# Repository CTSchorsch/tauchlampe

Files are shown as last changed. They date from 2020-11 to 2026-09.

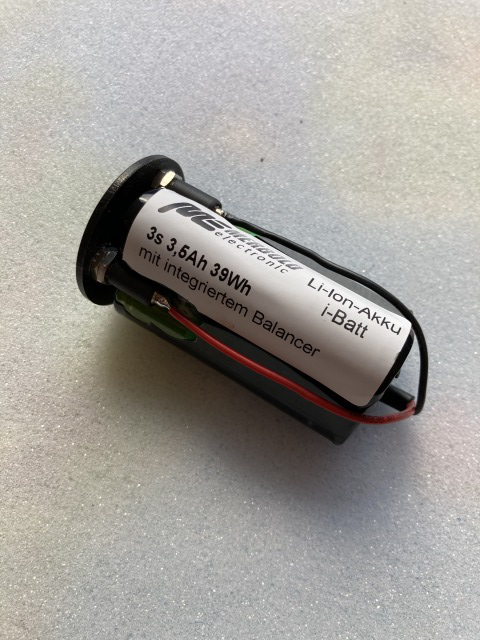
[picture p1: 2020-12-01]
doc/bilder/v4.2/Batteriefach8.JPG

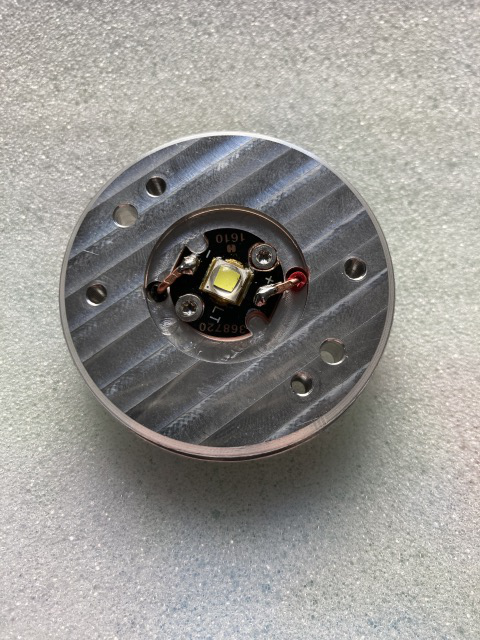
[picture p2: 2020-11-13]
doc/bilder/v4.2/led.jpg

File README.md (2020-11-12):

# tauchlampe

10W LED Tanklampe mit Goodmanhandle

Version 4.2
- neues PCB, einseitig, liegt direkt auf der LED-Aufnahme auf, JST Stecker für Taster und Power
- Abdeckung für PCB
- LED-Aufnahme für Produktion vereinfacht
- Deckel für Akkufach: 2 Bananenbuchsen zum laden, Durchführung für JST Kabel

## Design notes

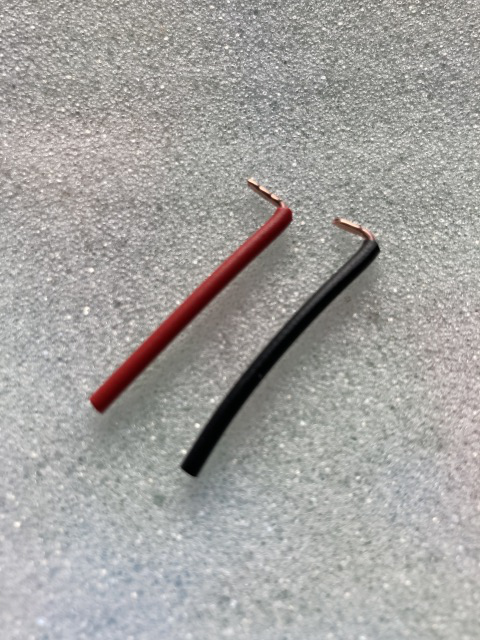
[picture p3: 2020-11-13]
doc/bilder/v4.2/zuleitung.jpg

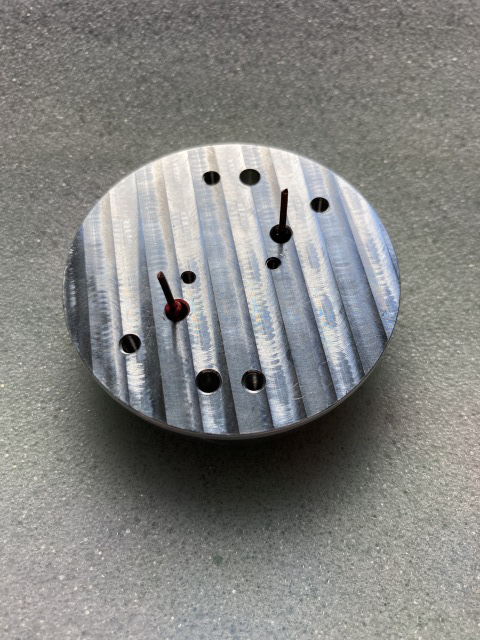
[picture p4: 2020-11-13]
doc/bilder/v4.2/led2.jpg

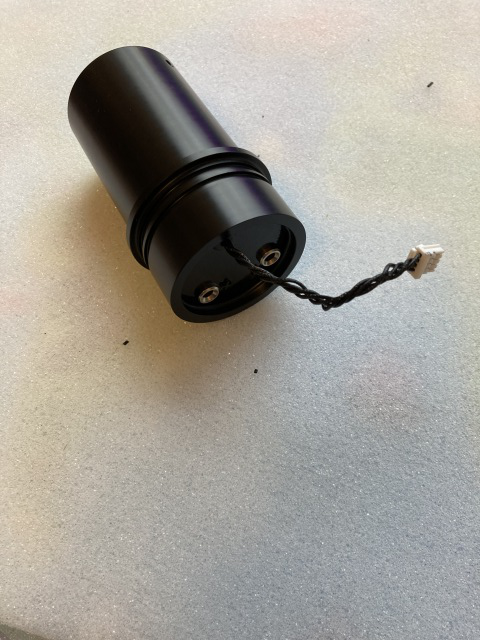
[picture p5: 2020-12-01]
doc/bilder/v4.2/Batteriefach12.JPG

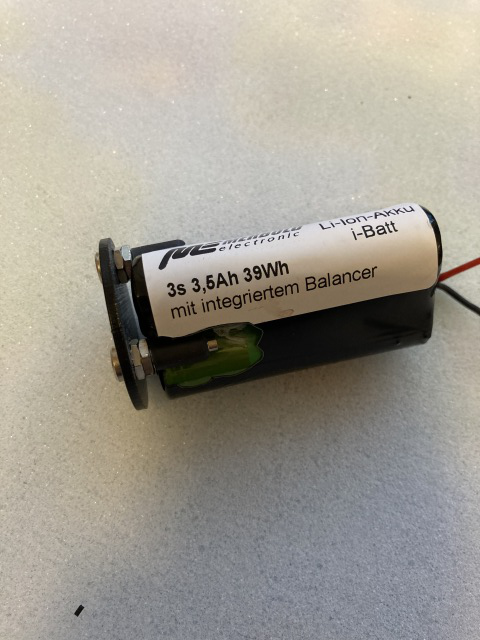
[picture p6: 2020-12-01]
doc/bilder/v4.2/Batteriefach7.JPG

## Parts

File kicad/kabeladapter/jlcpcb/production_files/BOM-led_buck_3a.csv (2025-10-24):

Comment | Designator | Footprint | LCSC | Quantity
MWSA0603-100MT | L1 | L_Sumida_CDMC6D28_7.25x6.5mm | C132141 | 1
MAX16820ATT | U1 | SON95P300X300X80-7N | C143371 | 1
10k0 | R2 | R_0805_2012Metric | C17414 | 1
4n70 | C7 | C_0805_2012Metric | C1744 | 1
4k75 | R5 | R_0805_2012Metric | C17672 | 1
68k1 | R4 | R_0805_2012Metric | C17771 | 1
825k | R3 | R_0805_2012Metric | C17835 | 1
SS54 | D1 | D_SMA | C22452 | 1
LED blau | D2 | LED_0805_2012Metric | C2293 | 1
22u0 / 25V | C4,C5 | C_0805_2012Metric | C45783 | 2
100n | C2,C6 | C_0805_2012Metric | C49678 | 2
0R070 | R1 | R_2512_6332Metric | C76251 | 1
22u0 / 25V | C1 | C_0805_2012Metric | C90143 | 1
Conn_02x03_Odd_Even | J3 | PinHeader_2x03_P2.00mm_Vertical_SMD |  | 1
ATtiny1616-M | U2 | VQFN-20-1EP_3x3mm_P0.4mm_EP1.7x1.7mm |  | 1
M1 | H1 | MountingHole_3.2mm_M3 |  | 1
M2 | H2 | MountingHole_3.2mm_M3 |  | 1
BSC022N04LSATMA | Q1 | TDSON-8-1 |  | 1
470r | R8 | R_0805_2012Metric |  | 1
TestPoint | TP1 | TestPoint_Pad_1.0x1.0mm |  | 1
Conn_01x05 | J4 | PinHeader_1x05_P2.00mm_Vertical |  | 1
TestPoint | TP4 | TestPoint_Pad_1.0x1.0mm |  | 1
LED+ | J1 | TestPoint_Plated_Hole_D3.0mm |  | 1
LED- | J2 | TestPoint_Plated_Hole_D3.0mm |  | 1

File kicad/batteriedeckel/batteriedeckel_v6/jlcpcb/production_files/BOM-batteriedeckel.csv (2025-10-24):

Comment | Designator | Footprint | LCSC | Quantity
Conn_02x03_Odd_Even | J1 | PinSocket_2x03_P2.00mm_Vertical_SMD |  | 1
MountingHole | H2 | MountingHole_3.2mm_M3_DIN965 |  | 1
MountingHole | H1 | MountingHole_3.2mm_M3_DIN965 |  | 1

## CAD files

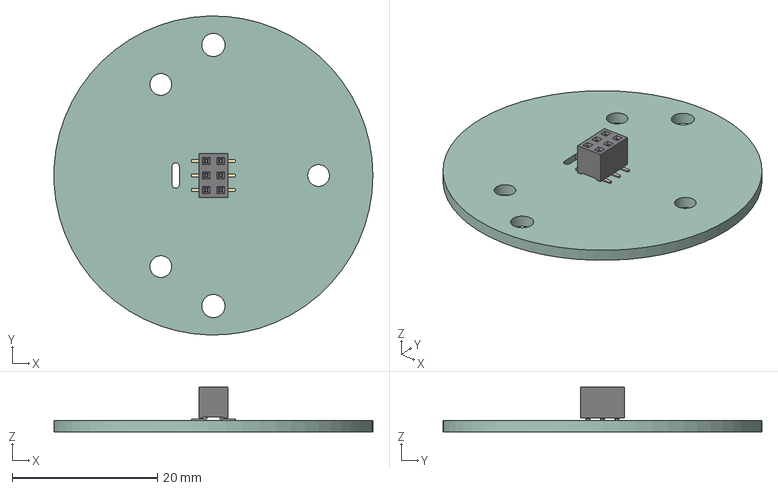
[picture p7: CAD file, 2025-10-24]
kicad/batteriedeckel/batteriedeckel_v6/batteriedeckel.step
44.0 x 44.0 x 6.20 mm
PinSocket_2x03_P2.00mm_Vertical_SMD
batteriedeckel_PCB

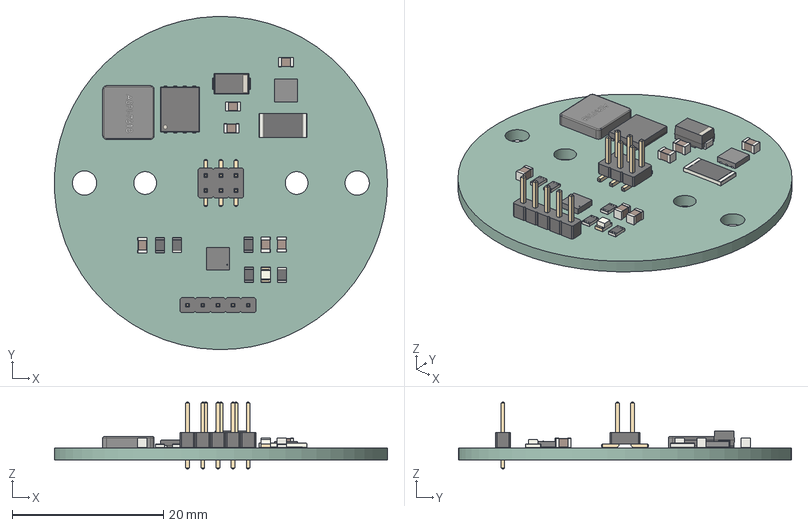
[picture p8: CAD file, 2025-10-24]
kicad/kabeladapter/kabeladapter.step
44.0 x 44.0 x 8.80 mm
C_0805_2012Metric x 6
D_SMA
LED_0805_2012Metric
R_0805_2012Metric x 5
PinHeader_2x03_P200mm_Vertical_SMD
T633+2
ASPI-7318
R_2512_6332Metric
TDSON_8_1
PinHeader_1x05_P200mm_Vertical
_autosave-led_buck_3a_PCB

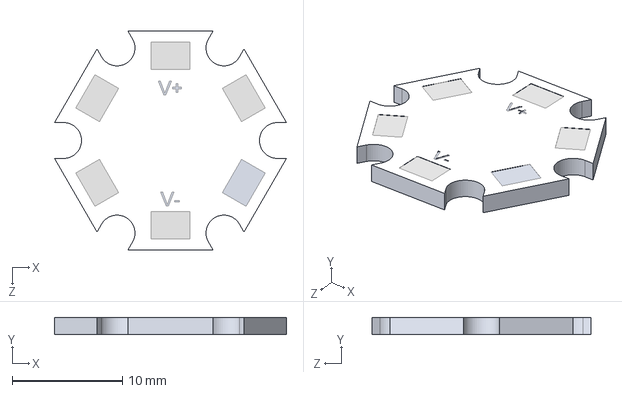
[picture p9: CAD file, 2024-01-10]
mech/cree/User Library-Star-PCB/User Library-Star-PCB.STEP
21.1 x 1.59 x 19.9 mm

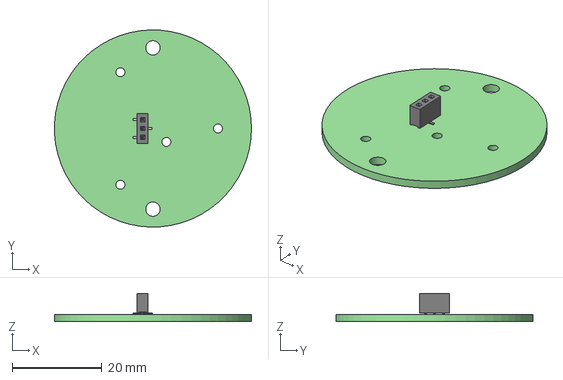
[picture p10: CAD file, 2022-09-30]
mech/PCBs/batteriedeckel.step
44.0 x 44.0 x 6.25 mm
batteriedeckel PCB

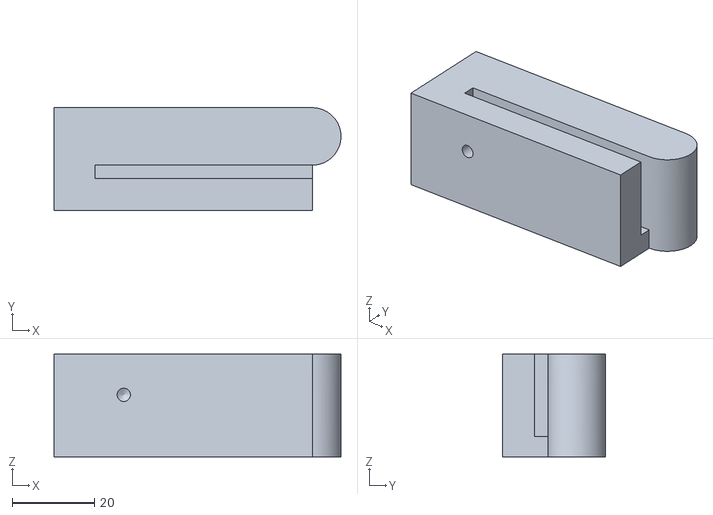
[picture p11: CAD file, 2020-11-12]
mech/Tools/Biegehilfe/Biegehilfe.stl
69.9 x 25.0 x 25.0

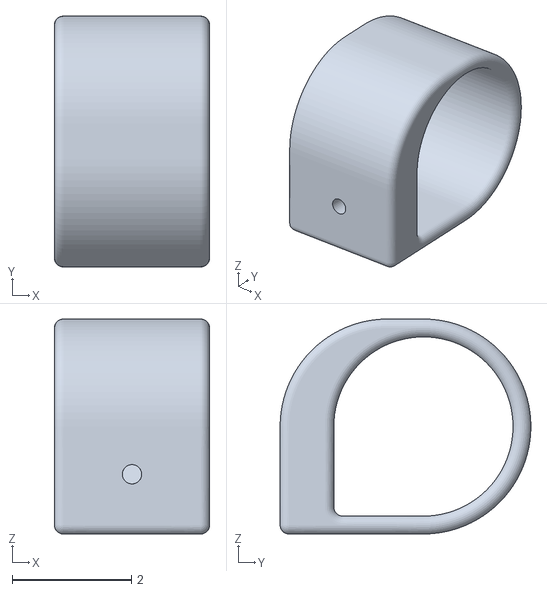
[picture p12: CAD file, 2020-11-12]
mech/Tools/Thumbloop/LoopD.stl
2.60 x 4.20 x 3.60

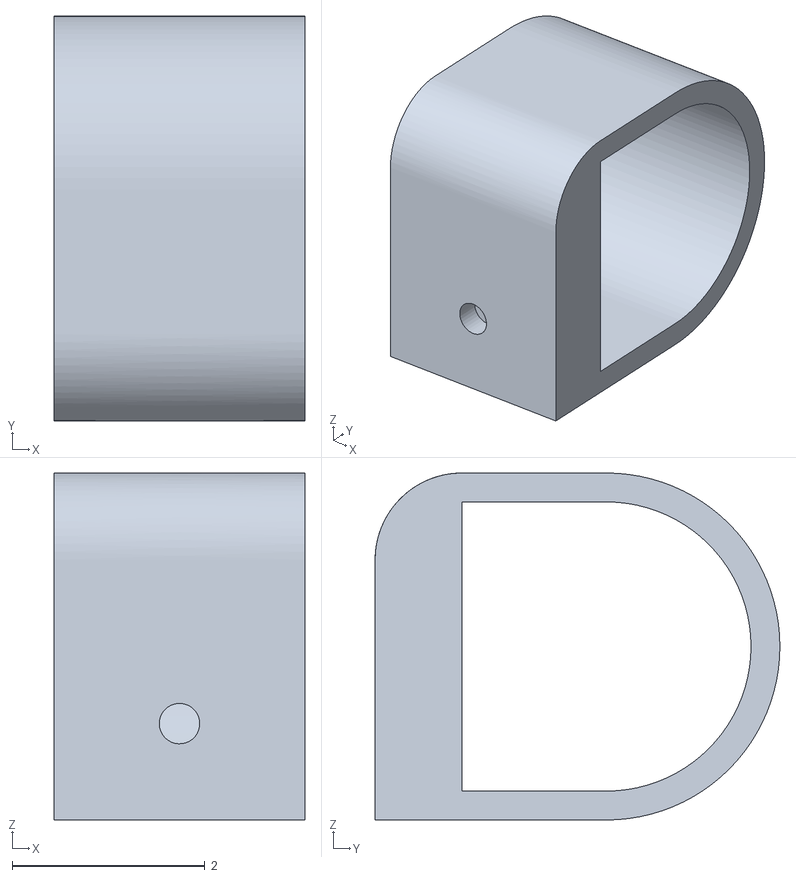
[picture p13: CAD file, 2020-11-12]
mech/Tools/Thumbloop/thumbloopB.stl
2.60 x 4.20 x 3.60

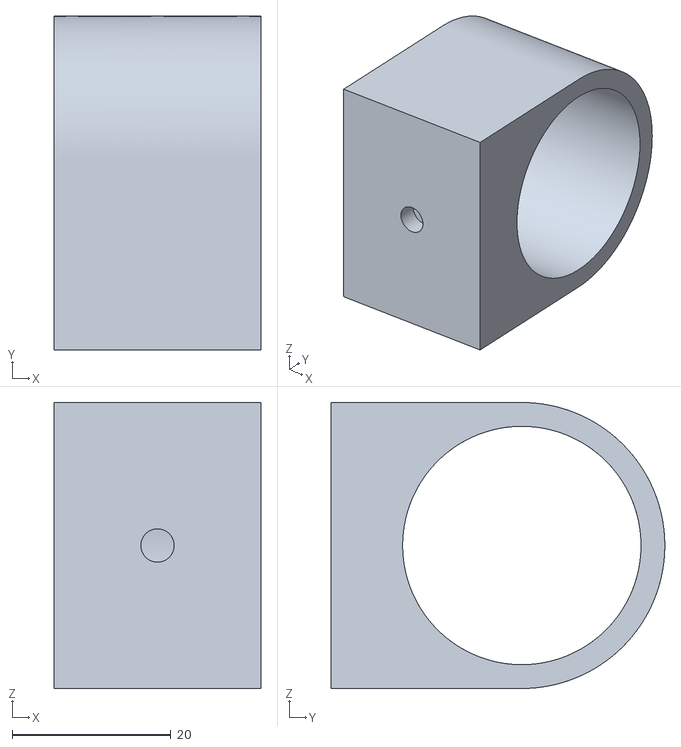
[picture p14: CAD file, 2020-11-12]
mech/Tools/Thumbloop/Bauteil1.stl
26.0 x 42.0 x 36.0

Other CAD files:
mech/Deckel.ipt
mech/Glasscheibe.ipt
mech/Grundplattee.ipt
mech/GrundplatteeThumbloop.ipt
mech/Halteblech.ipt
mech/Haltegriff.ipt
mech/Lampengehäuse.iam
mech/Lampengehäuse.ipt
mech/Lampengehäuse_detail.idw
mech/Lampenkopf.iam
mech/Lampenkopf_4_3.idw
mech/Langmutter.ipt
mech/Ledaufnahme.ipt
mech/O-Ring_40_1_8.ipt
mech/O-Ring_46x1.5.ipt
mech/O-Ring_48_2.ipt
mech/O-Ring_51_2.ipt
mech/O-Ring_51_3.ipt
mech/O-Ring_53_2_5.ipt
mech/O-Ring_55_2.ipt
mech/PCBs/ASPI-7318-100M-T--3DModel-STEP-400430.iam
mech/PCBs/B3B-PH-SM4-TB-LF--SN---3DModel-STEP-56544.iam
mech/PCBs/COMPOUND.ipt
mech/PCBs/COMPOUND_1.ipt
mech/PCBs/COMPOUND_2.ipt
mech/PCBs/C_0805_2012Metric.iam
mech/PCBs/D_SMA.iam
mech/PCBs/LED_0805_2012Metric.iam
mech/PCBs/MAX16820ATT+.iam
mech/PCBs/OldVersions/SOLID.0001.ipt
mech/PCBs/PinHeader_1x05_P2.00mm_Vertical.iam
mech/PCBs/PinSocket_1x03_P2.00mm_Vertical_SMD_Pin1Left.iam
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

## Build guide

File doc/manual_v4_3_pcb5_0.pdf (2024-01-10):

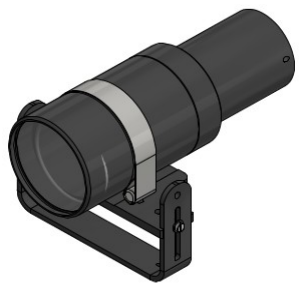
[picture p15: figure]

### Batterien einlegen A

3 Zellen vom Typ 18650 mit hohem Pluspol (button top)

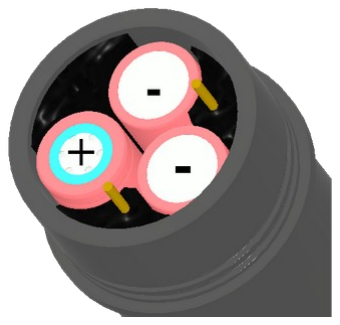
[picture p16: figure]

Flache Zellen können nur verwendet werden wenn die Batteriekontakte mit Lötzinn erhöht werden.

### georg@atc-ev.de

## 10W LED Tauchlampe

Bedienungsanleitung
v4.3a / PCB 5.0

### Inhalt / Hinweis

### Batterien einlegen | A Einschalten und Dimmen | B Umbau auf Kabel / Akkufach | C

Bei einer Akkuspannung von unter 9,2V oder einer Temperatur von >70°C in der Lampe, wird auf 20% gedimmt.

### Einschalten / Dimmen B

Akkufach: „langsames“ Doppeldrücken schaltet EIN, jedes weitere Drücken dimmt auf 70%, 30% und AUS.

Tank: EIN/AUS über Schalter am Tank. Wiederholtes AUS/EIN schalten innerhalb von 5 Sekunden dimmt in den Stufen 100%, 70% und 30%

### Umbau auf Kabel / Akkufach C

Der Anschluss für das Kabel ist unter den Akkukontakten

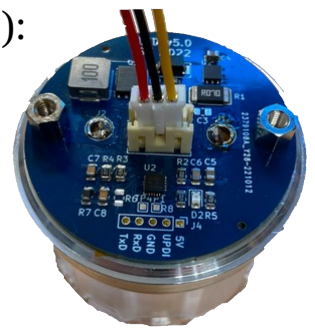
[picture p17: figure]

im Lampengehäuse (2 Schrauben lösen):

- Gelb + Pol (9-18V)
- Schwarz – Pol
- Rot „Modus“ Kontakt:
Für externen Akkutank rot mit schwarz verbinden

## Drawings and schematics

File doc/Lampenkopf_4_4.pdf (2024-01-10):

# D D 10W LED Lampenkopf

# (c) 2020 Georg Schardt

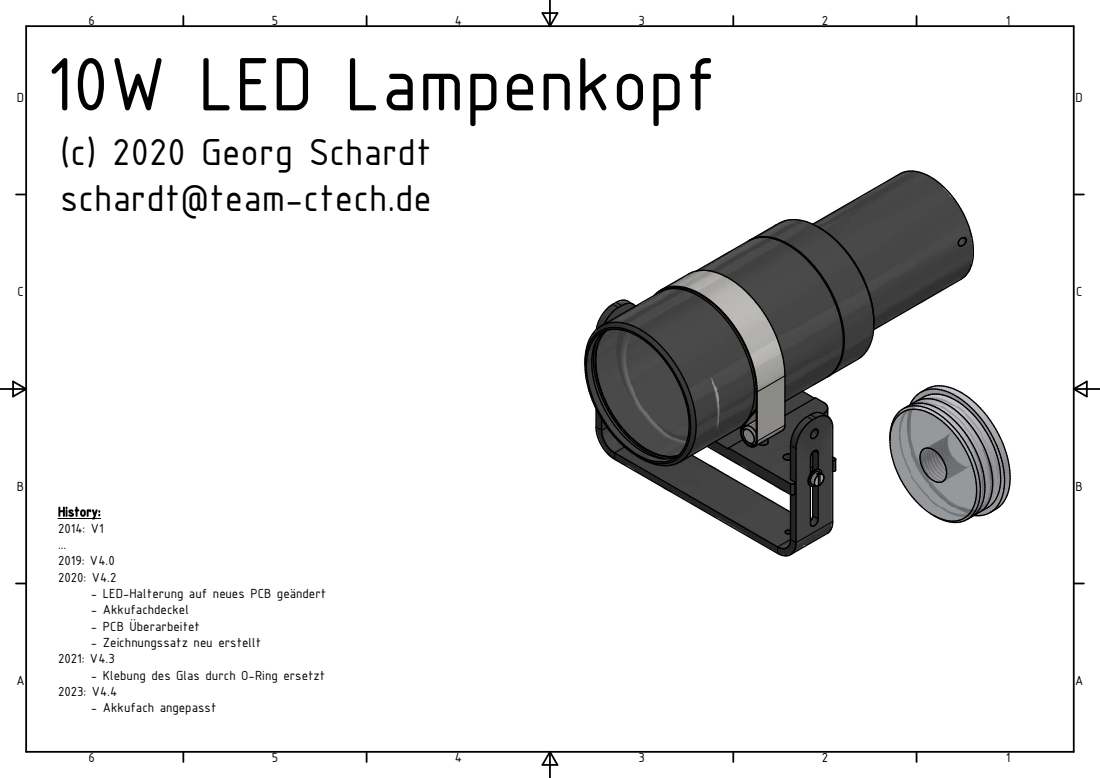
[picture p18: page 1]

schardt@team-ctech.de

History:
- LED-Halterung auf neues PCB geändert
- Akkufachdeckel
- PCB Überarbeitet
- Zeichnungssatz neu erstellt
- Klebung des Glas durch O-Ring ersetzt
- Akkufach angepasst

A A

B B

C C

D D

BAUTEILLISTE
OBJEKT | ANZAHL | BAUTEILNUMMER | BESCHREIBUNG
1 | 1 | GrundplatteeThumbloop
2 | 1 | Lampengehäuse
3 | 1 | Borosilikatglas 55x10
4 | 1 | Ledaufnahme
5 | 1 | Akkufach
6 | 1 | Überwurfmutter
7 | 1 | Haltegriff
8 | 1 | Halteblech
9 | 1 | PCB Buck_3a_v4 | KiCad electronic assembly
10 | 2 | Langmutter
11 | 1 | Gaggione LLH09SPB00 | 3D InterOp IGES (Version 22 0 2), Spatial Corp. Copyright (c) 1999-2007.
12 | 2 | BS 4168 - M4 x 16 | Senkkopf- und Halbrundschrauben mit Innensechskant -metrische Ausführung
13 | 2 | DIN 125 - A 3,2 | Unterlegscheibe
14 | 2 | ISO 1207 - M3 x 4 | Zylinderschraube mit Schlitz
15 | 1 | Gaggione LLC49N
16 | 1 | O-Ring_51_2
17 | 2 | O-Ring_46x1.5
18 | 1 | O-Ring_55_2
19 | 1 | O-Ring_48_2
20 | 1 | O-Ring_40_1_8
21 | 1 | akkuhalterung_deckel_2

C C

D

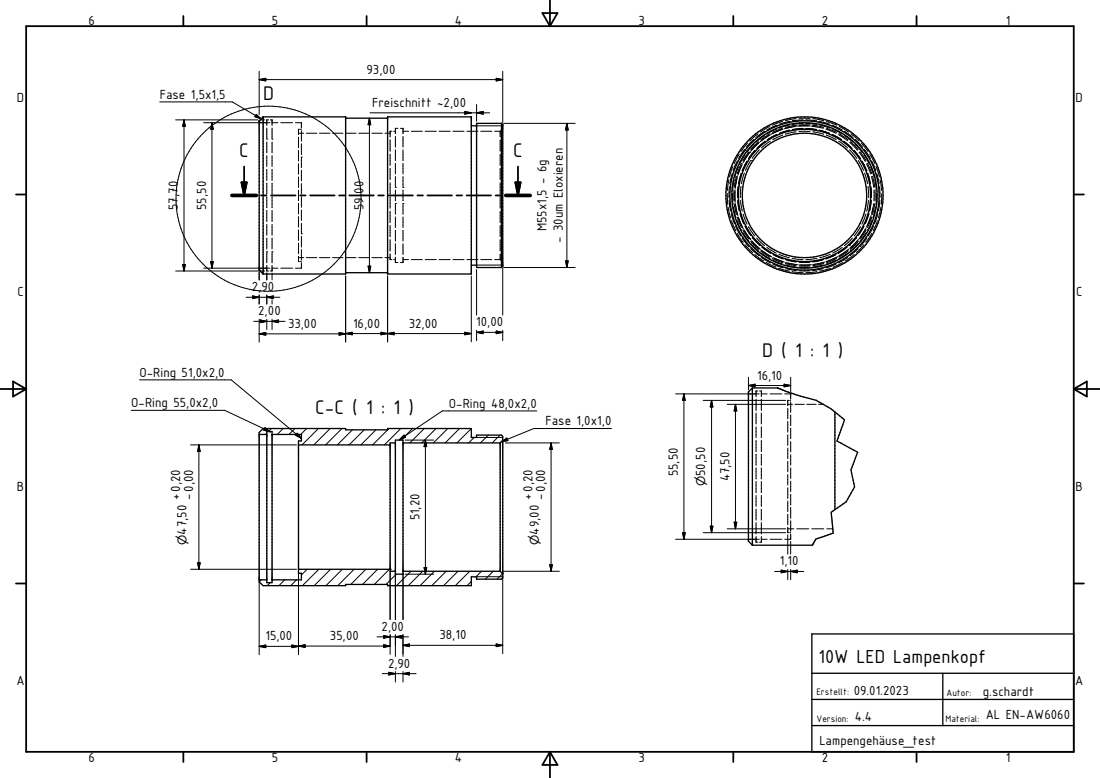
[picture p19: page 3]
Version:; 10W LED Lampenkopf; Material:; Freischnitt ~2,00; M⁵⁵x¹,5 - 6g - 30um Eloxieren 59,00; Fase 1,5x1,5; Fase 1,0x1,0; O-Ring 48,0x2,0; O-Ring 55,0x2,0; O-Ring 51,0x2,0 ⁵⁵,50

Erstellt: 09.01.2023 | Autor: g.schardt

Lampengehäuse_test

## B B 4⁸,80

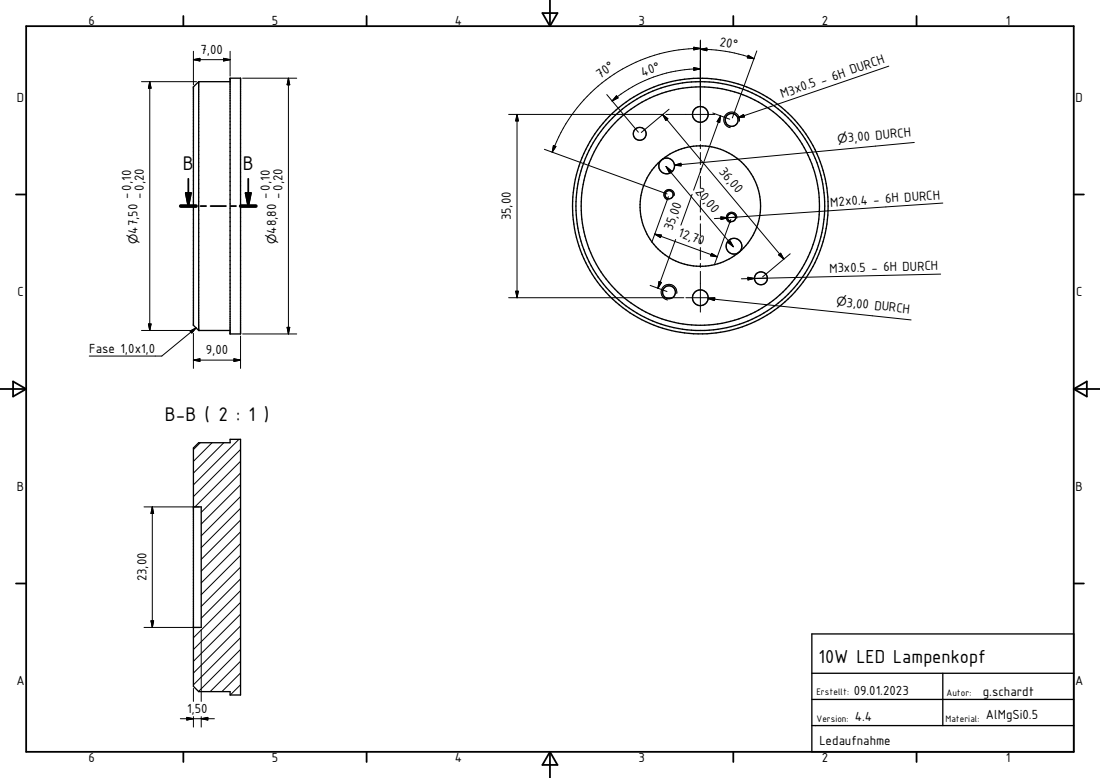
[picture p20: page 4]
10W LED Lampenkopf; Fase 1,0x1,0 ⁴⁷,50; M3x0.5 - 6H DURCH; n3,00 DURCH; M2x0.4 - 6H DURCH; AlMgSi0.5

Erstellt: 09.01.2023 | Autor: g.schardt

Ledaufnahme

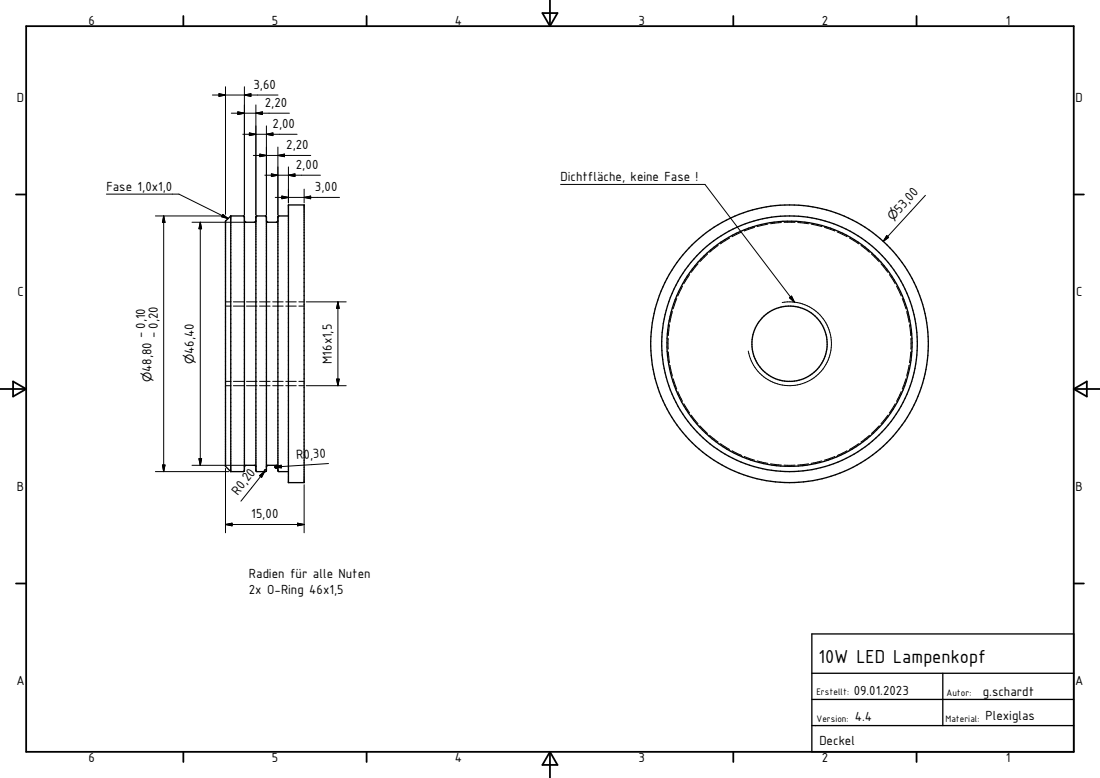
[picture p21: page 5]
10W LED Lampenkopf; 2x O-Ring 46x1,5M¹⁶x¹,5 4⁸,80; Fase 1,0x1,0; Plexiglas

Dichtfläche, keine Fase !

Radien für alle Nuten

Erstellt: 09.01.2023 | Autor: g.schardt

Deckel

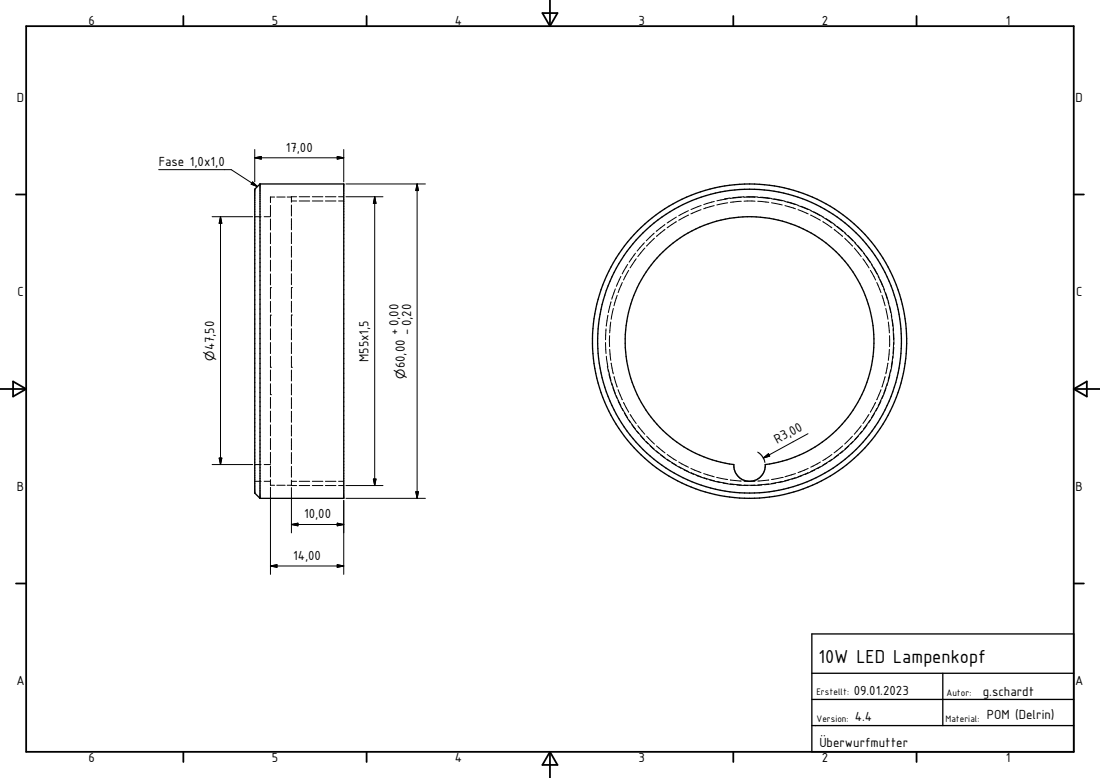
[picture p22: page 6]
10W LED Lampenkopf; Fase 1,0x1,0; POM (Delrin)

Erstellt: 09.01.2023 | Autor: g.schardt

Überwurfmutter

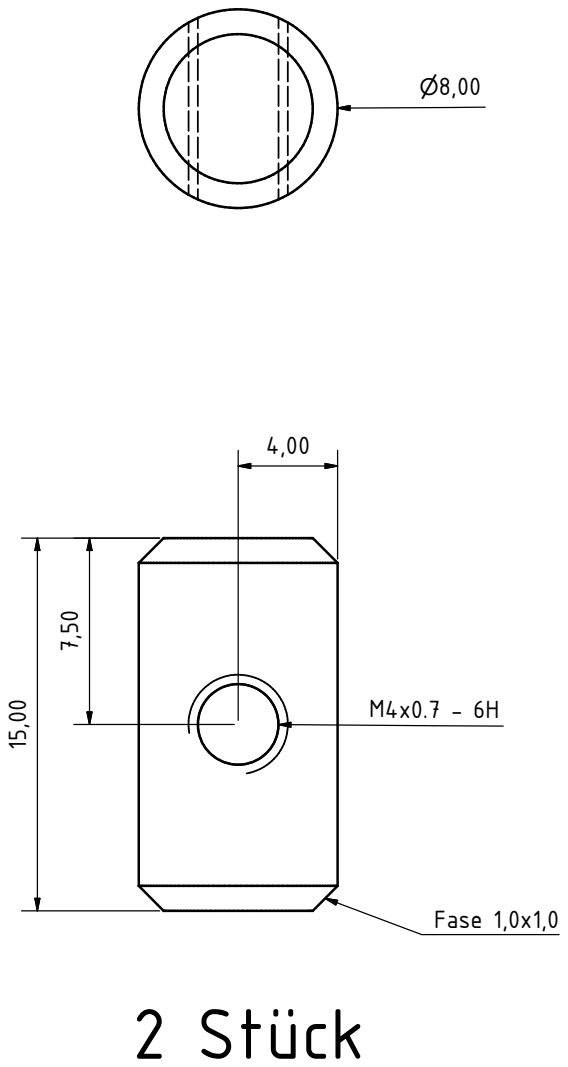
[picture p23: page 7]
10W LED Lampenkopf; Fase 1,0x1,0; 2 Stück

Erstellt: 09.01.2023 | Autor: g.schardt

LANGMUTTER

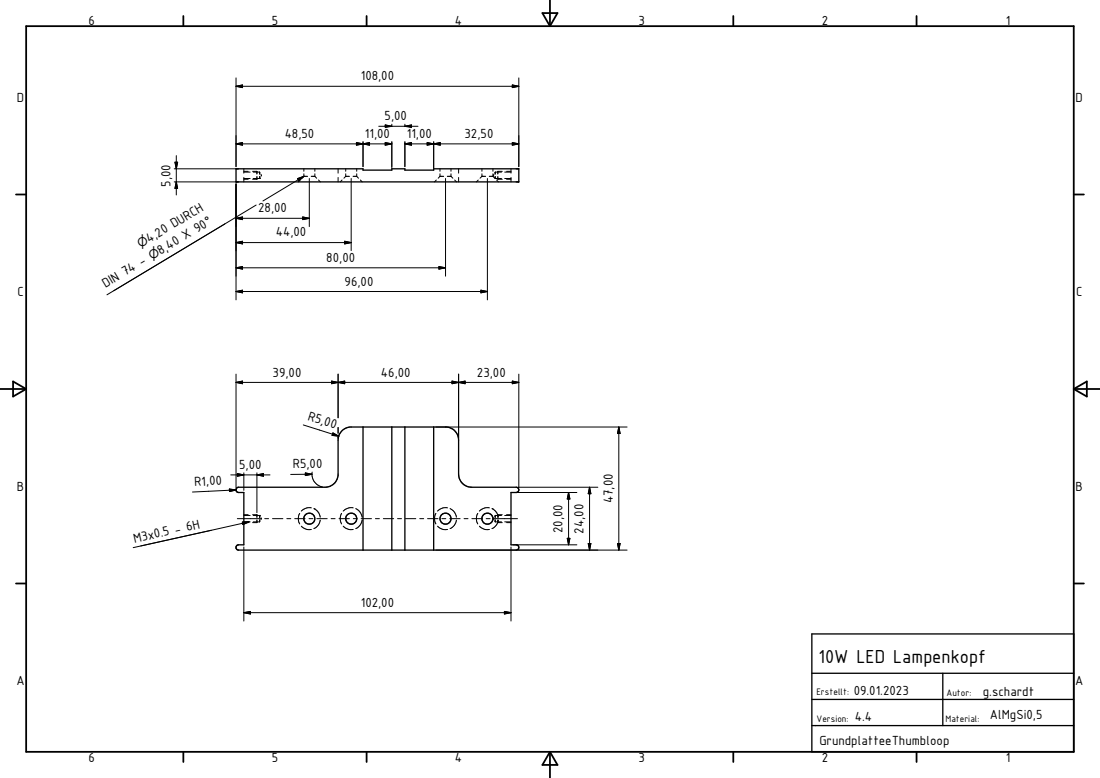
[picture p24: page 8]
10W LED Lampenkopf; Material: AlMgSi0,5 ⁵,00; n4,20 DURCH DIN 74 - n8,40 X 90°

Erstellt: 09.01.2023 | Autor: g.schardt

GrundplatteeThumbloop

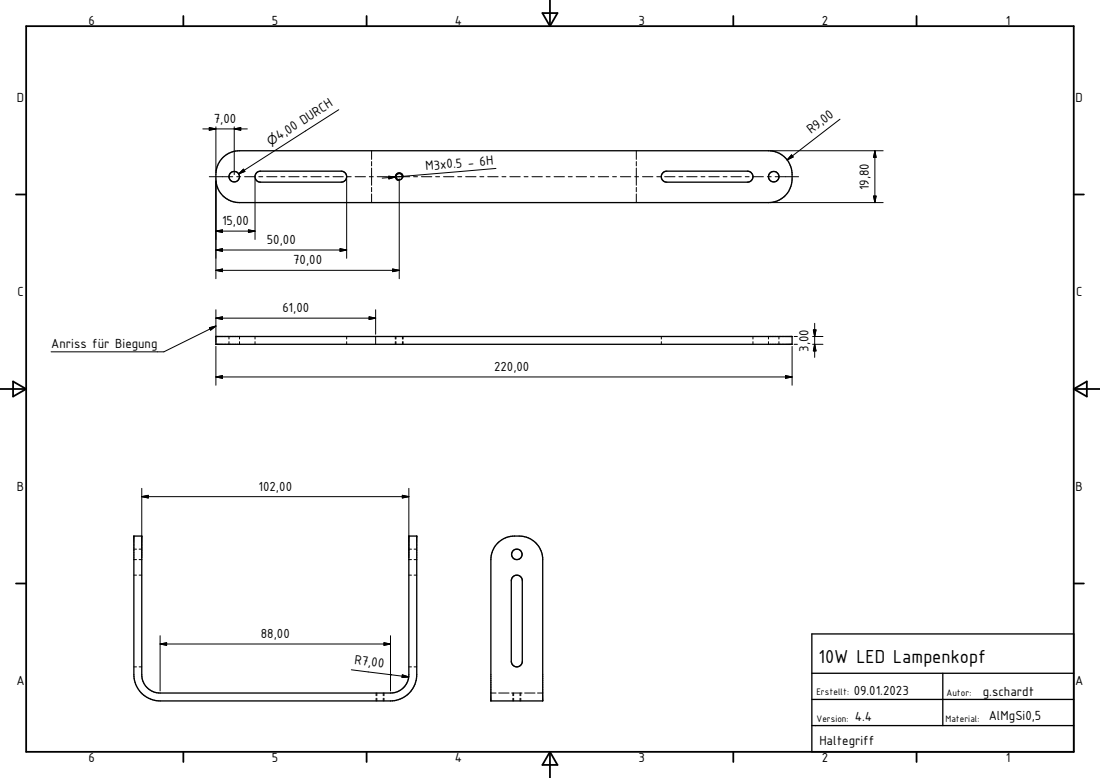
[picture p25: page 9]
Haltegriff; 10W LED Lampenkopf; n4,00 DURCH

Anriss für Biegung

Erstellt: 09.01.2023 | Autor: g.schardt
4.4 | AlMgSi0,5

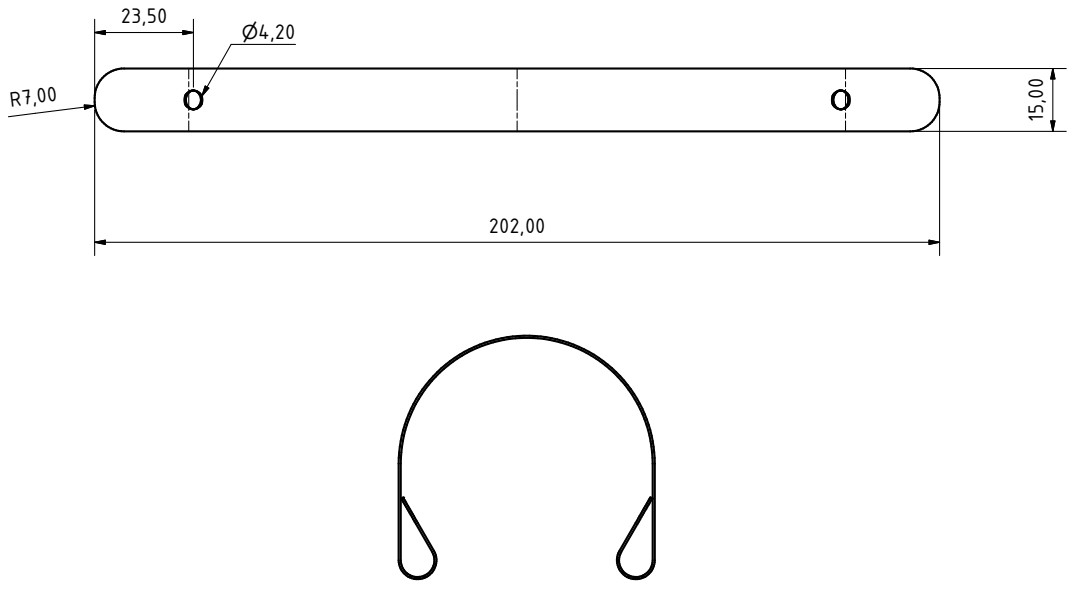
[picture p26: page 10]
10W LED Lampenkopf

Erstellt: 09.01.2023 | Autor: g.schardt

Halteblech

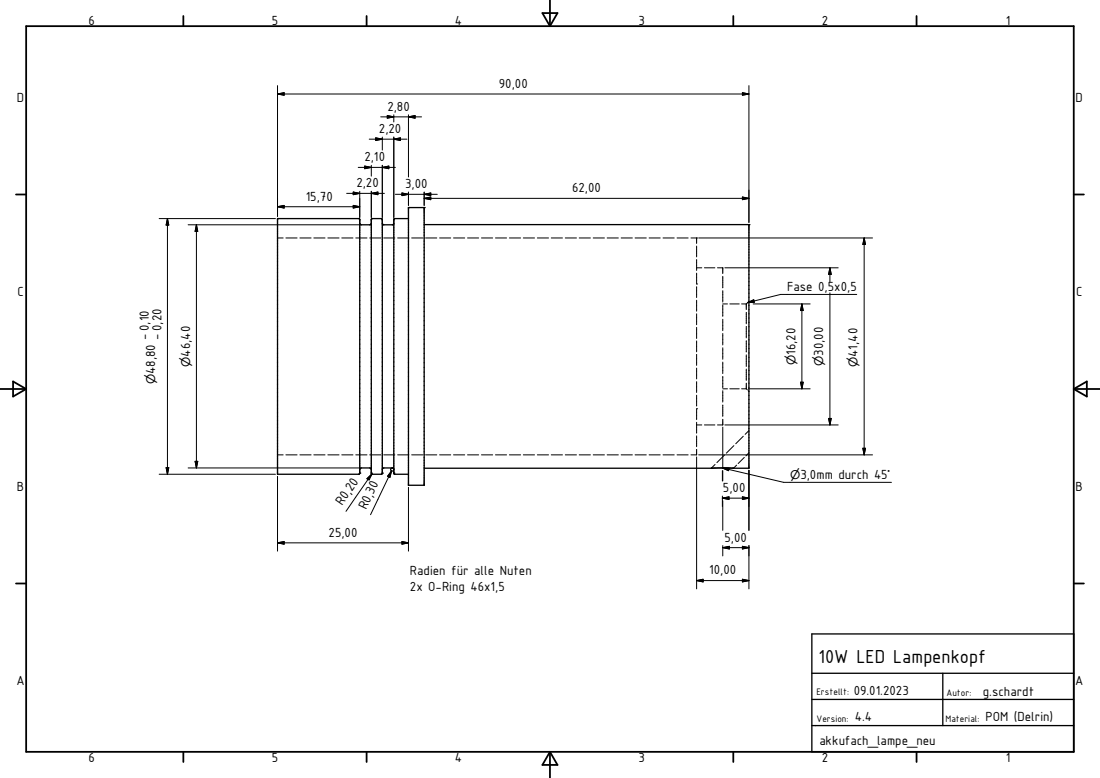
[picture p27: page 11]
10W LED Lampenkopf; Fase 0,5x0,5; n3,0mm durch 45~; POM (Delrin)

Radien für alle Nuten
2x O-Ring 46x1,5

Erstellt: 09.01.2023 | Autor: g.schardt

akkufach_lampe_neu

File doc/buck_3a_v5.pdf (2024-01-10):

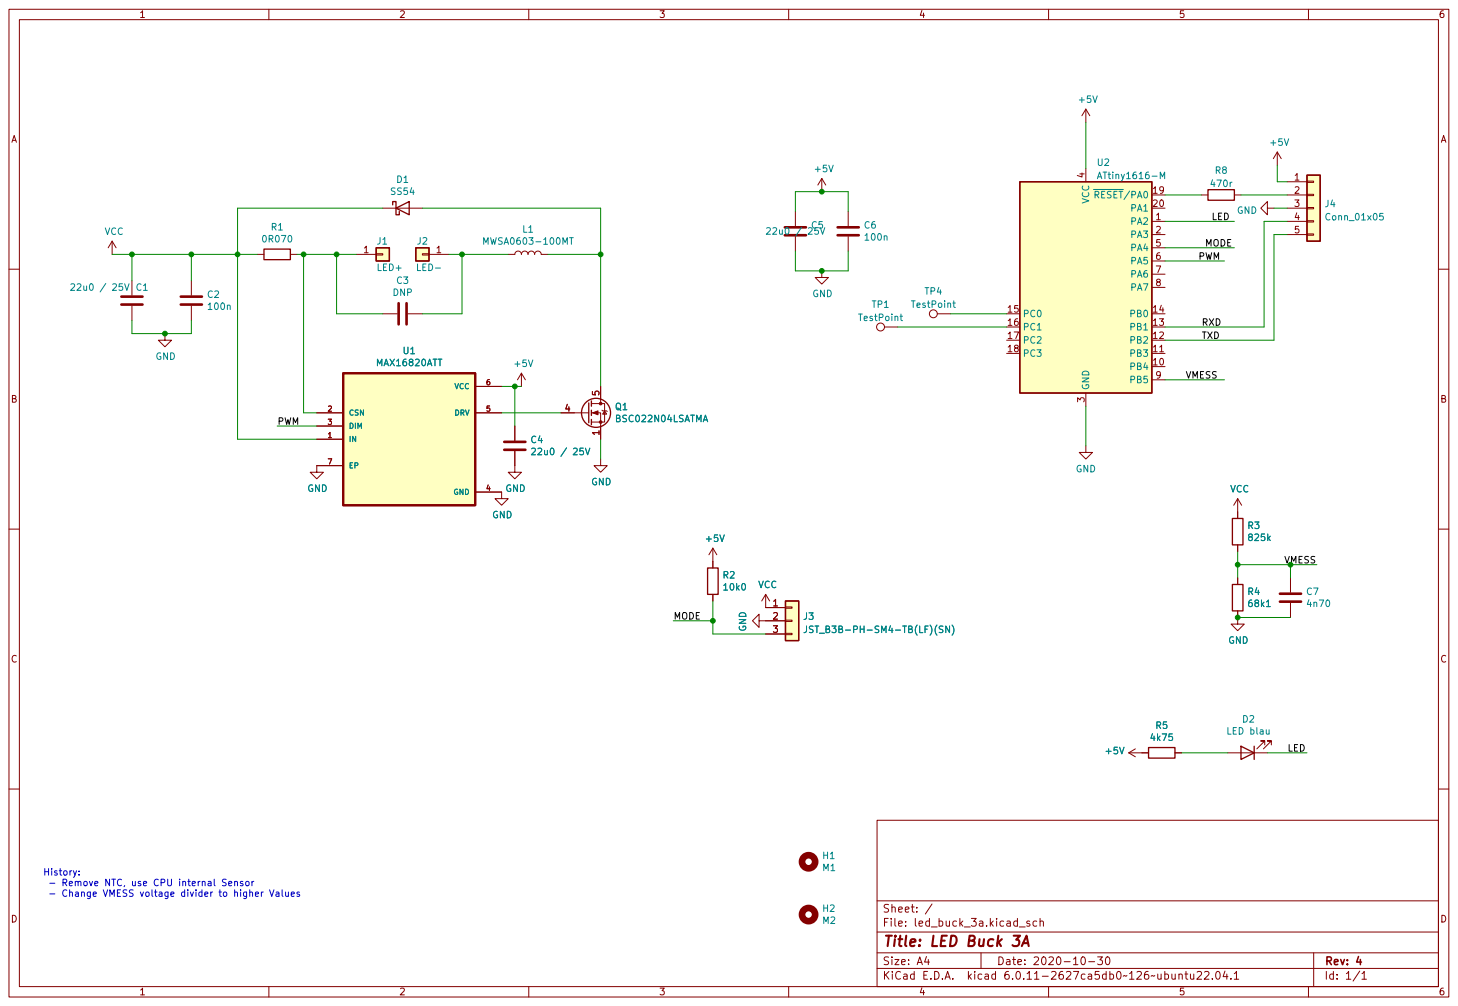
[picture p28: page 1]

JST_B3B-PH-SM4-TB(LF)(SN) 1

File: led_buck_3a.kicad_sch Sheet: /
Id: 1/1 Title: LED Buck 3A

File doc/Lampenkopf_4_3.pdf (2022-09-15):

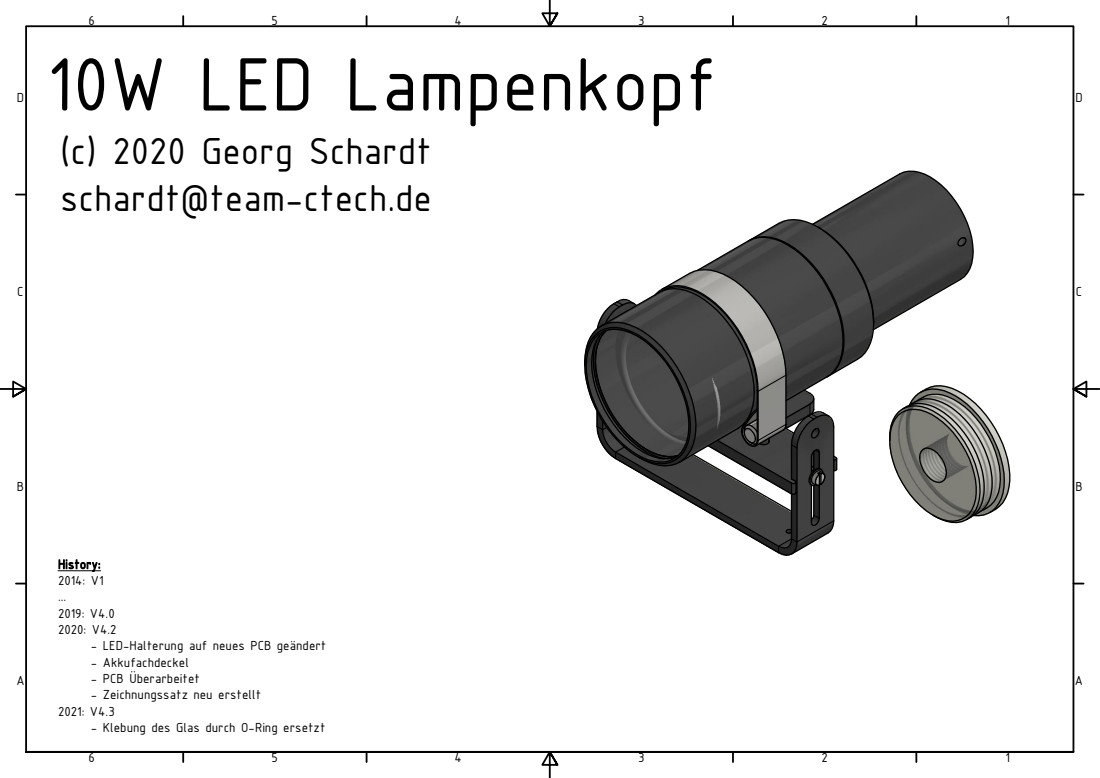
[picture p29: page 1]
10W LED Lampenkopf

(c) 2020 Georg Schardt
schardt@team-ctech.de

History:
- LED-Halterung auf neues PCB gendert
- Akkufachdeckel
- PCB berarbeitet
- Zeichnungssatz neu erstellt
- Klebung des Glas durch O-Ring ersetzt

BAUTEILLISTE
OBJEKT | ANZAHL | BAUTEILNUMMER | BESCHREIBUNG
1 | 1 | Grundplatte
2 | 1 | Lampengehuse
3 | 1 | Borosilikatglas 55x10
4 | 1 | Ledaufnahme
5 | 1 | Akkufach
6 | 1 | berwurfmutter
7 | 1 | Haltegriff
8 | 1 | Halteblech
9 | 1 | PCB Buck_3a_v4 | KiCad electronic assembly
10 | 2 | Langmutter
11 | 1 | Gaggione LLH09SPB00 | 3D InterOp IGES (Version 22 0 2), Spatial Corp. Copyright (c) 1999-2007.
12 | 2 | BS 4168 - M4 x 16 | Senkkopf- und Halbrundschrauben mit Innensechskant -metrische Ausf¯hrung
13 | 2 | DIN 125 - A 3,2 | Unterlegscheibe
14 | 2 | ISO 1207 - M3 x 4 | Zylinderschraube mit Schlitz
15 | 1 | Gaggione LLC49N
16 | 1 | O-Ring_51_2
17 | 2 | O-Ring_46x1.5
18 | 1 | O-Ring_55_2
19 | 1 | O-Ring_48_2
20 | 1 | O-Ring_40_1_8
21 | 1 | akkuhalterung_deckel_2
A | A
B | B
C | C
D | D

10W LED Lampenkopf; Freischnitt ~2,00; Fase 1,5x1,5; Fase 1,0x1,0; O-Ring 48,0x2,0; O-Ring 55,0x2,0; O-Ring 51,0x2,0

Material: AL EN-AW6060

10W LED Lampenkopf; Fase 1,0x1,0; M3x0.5 - 6H DURCH; M2x0.4 - 6H DURCH

10W LED Lampenkopf; Fase 1,0x1,0

Dichtflche, keine Fase !

Radien f¯r alle Nuten
2x O-Ring 46x1,5

10W LED Lampenkopf; Fase 1,0x1,0; POM (Delrin)

10W LED Lampenkopf; Fase 1,0x1,0

n: Grund

10W LED Lampenkopf

12.11.2020 Erstellt: | Autor: g.schardt

AlMgSi0,5

10W LED Lampenkopf

10W LED Lampenkopf; Fase 0,5x0,5; POM (Delrin)

Radien f¯r alle Nuten
2x O-Ring 46x1,5

10W LED Lampenkopf; Material: 3D Druck; Dicke 2,3mm

Gummit¯lle f¯r 3mm Bohrung
Auendurchmesser 8mm

10W LED Lampenkopf; Material: 3D Druck

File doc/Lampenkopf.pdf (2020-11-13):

10W LED Lampenkopf

(c) 2020 Georg Schardt
schardt@team-ctech.de

History:
- LED-Halterung auf neues PCB gendert
- Akkufachdeckel
- PCB berarbeitet
- Zeichnungssatz neu erstellt

BAUTEILLISTE
OBJEKT | ANZAHL | BAUTEILNUMMER | BESCHREIBUNG
1 | 1 | Grundplatte
2 | 1 | Lampengehuse
3 | 1 | Borosilikatglas 55x10
4 | 1 | Ledaufnahme
5 | 1 | Akkufach
6 | 1 | berwurfmutter
7 | 1 | Haltegriff
8 | 1 | Halteblech
9 | 1 | PCB Buck_3a_v4 | KiCad electronic assembly
10 | 2 | Langmutter
11 | 1 | Gaggione LLH09SPB00 | 3D InterOp IGES (Version 22 0 2), Spatial Corp. Copyright (c) 1999-2007.
12 | 2 | BS 4168 - M4 x 16 | Senkkopf- und Halbrundschrauben mit Innensechskant -metrische Ausf¯hrung
13 | 2 | DIN 125 - A 3,2 | Unterlegscheibe
14 | 2 | ISO 1207 - M3 x 4 | Zylinderschraube mit Schlitz
15 | 1 | Gaggione LLC49N
16 | 1 | O-Ring_51_3
17 | 2 | O-Ring_46x1.5
A | A
B | B
C | C
D | D

10W LED Lampenkopf; Fase 1.5x1.5; Fase 1,0x1,0; Freischnitt ~2,0; O-Ring 51,00x3,00; Klebung Glas:

Marina Silikonkleber klar

10W LED Lampenkopf; Fase 1,0x1,0

10W LED Lampenkopf; Fase 1,0x1,0

Dichtflche, keine Fase !

Radien f¯r alle Nuten
2x O-Ring 46x1,5

10W LED Lampenkopf; Fase 1,0x1,0; POM (Delrin)

10W LED Lampenkopf; Fase 1,0x1,0

n: Grund

10W LED Lampenkopf

12.11.2020 Erstellt: | Autor: g.schardt

AlMgSi0,5

10W LED Lampenkopf

10W LED Lampenkopf; Fase 0,5x0,5; POM (Delrin)

Radien f¯r alle Nuten
2x O-Ring 46x1,5

10W LED Lampenkopf; Material: 3D Druck

10W LED Lampenkopf; Material: 3D Druck

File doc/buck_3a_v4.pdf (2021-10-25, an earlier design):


8 U2 ATtiny45-20SU
TMESS RESET RESET MODE

File: buck_3a_v4.sch Sheet: / GND

Id: 1/1 Title: LED Buck 3A

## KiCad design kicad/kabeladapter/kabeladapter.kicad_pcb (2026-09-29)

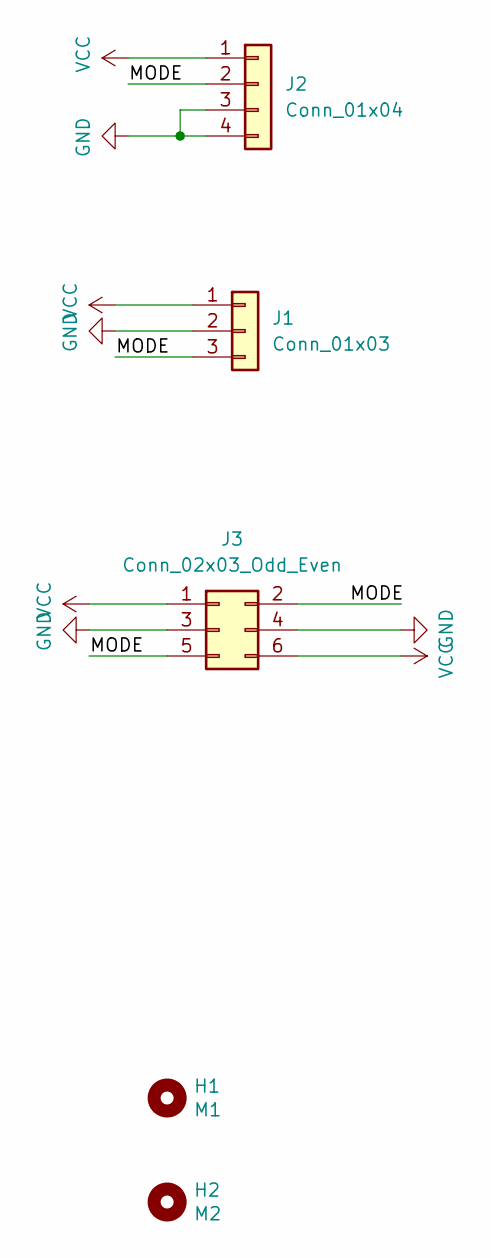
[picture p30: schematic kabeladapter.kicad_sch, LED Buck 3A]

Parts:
H1: M1; MountingHole_3.2mm_M3
H2: M2; MountingHole_3.2mm_M3
J1: Conn_01x03; JST_PH_B3B-PH-SM4-TB_1x03-1MP_P2.00mm_Vertical
J2: Conn_01x04; JST_GH_BM04B-GHS-TBT_1x04-1MP_P1.25mm_Vertical
J3: Conn_02x03_Odd_Even; PinHeader_2x03_P2.00mm_Vertical_SMD

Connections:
/MODE: J1.3, J2.2, J3.2, J3.5
GND: J1.2, J2.3, J2.4, J3.3, J3.4
VCC: J1.1, J2.1, J3.1, J3.6

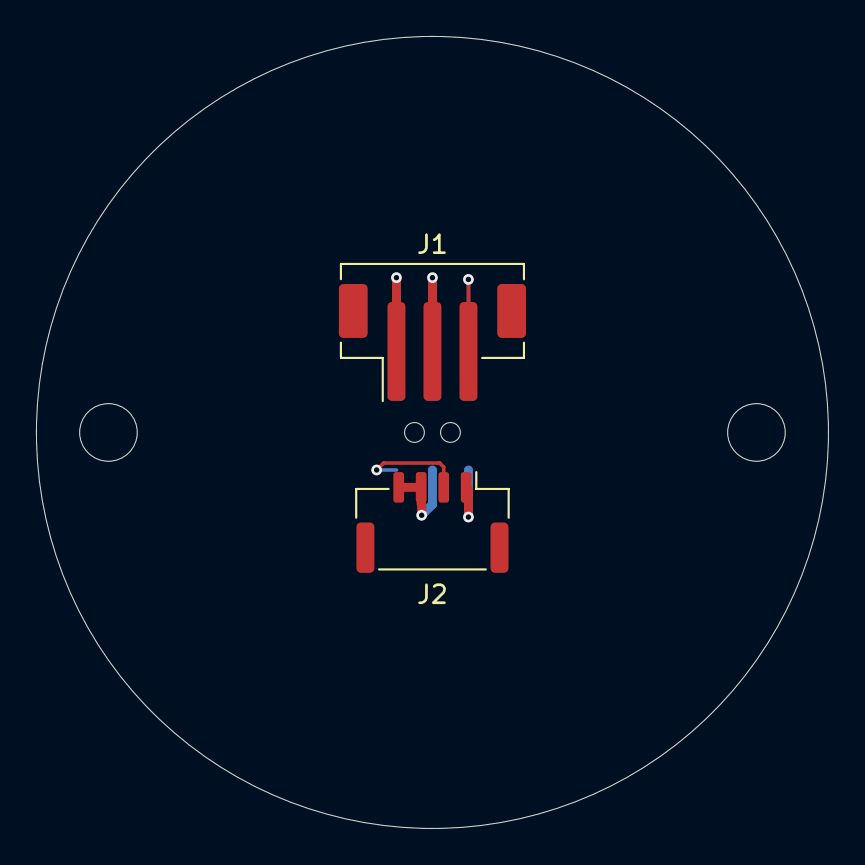
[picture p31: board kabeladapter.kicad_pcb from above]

Board: 2 copper layers, 44.0 x 44.0 mm, 5 parts (1 on the bottom side), 3 nets.

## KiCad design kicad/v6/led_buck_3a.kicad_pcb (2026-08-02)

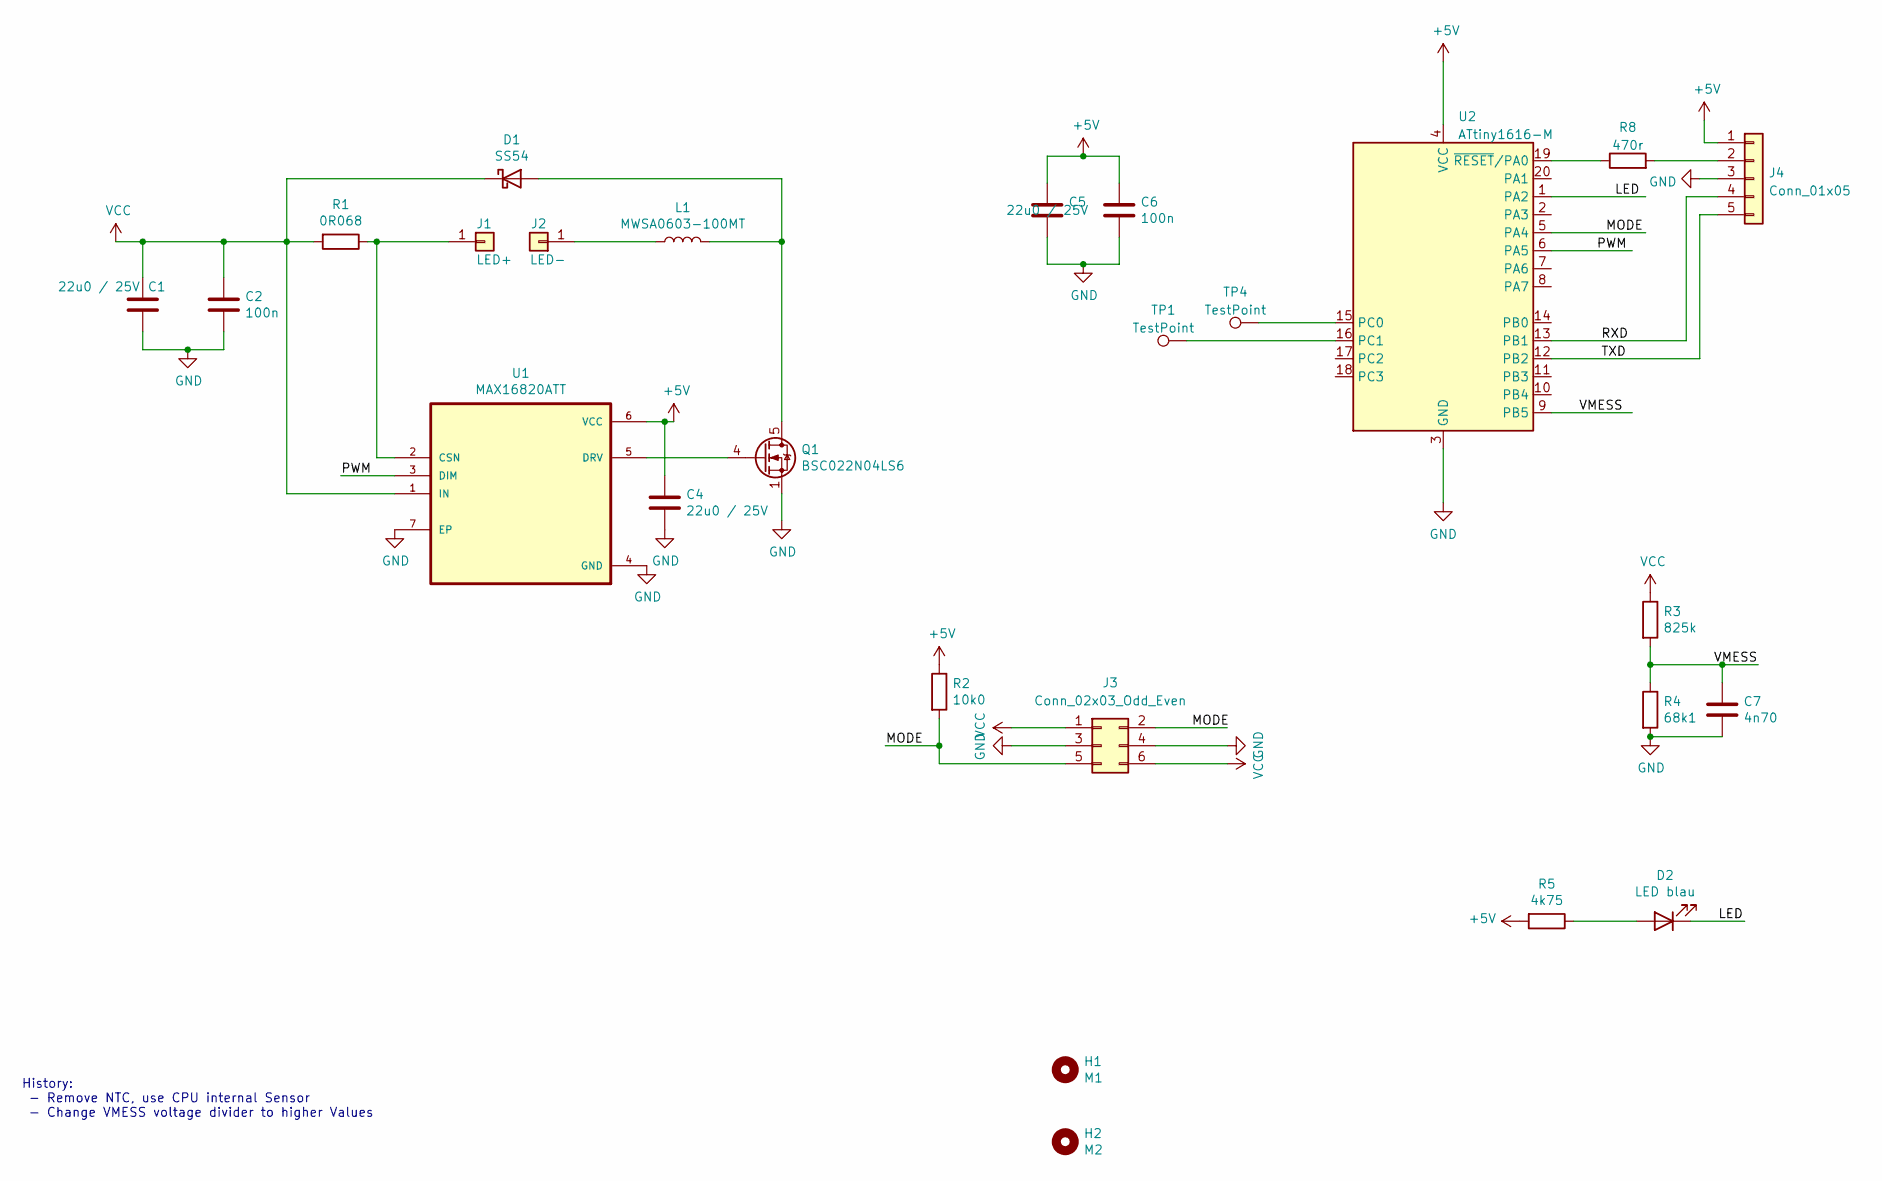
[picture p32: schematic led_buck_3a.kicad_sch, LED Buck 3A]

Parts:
C1, C4, C5: 22u0 / 25V; C_0805_2012Metric; LCSC C45783
C2, C6: 100n; C_0805_2012Metric; LCSC C49678
C7: 4n70; C_0805_2012Metric; LCSC C1744
D1: SS54; D_SMA; LCSC C22452
D2: LED blau; LED_0805_2012Metric; LCSC C2293
H1: M1; MountingHole_3.2mm_M3
H2: M2; MountingHole_3.2mm_M3
J1: LED+; TestPoint_Plated_Hole_D3.0mm
J2: LED-; TestPoint_Plated_Hole_D3.0mm
J3: Conn_02x03_Odd_Even; PinHeader_2x03_P2.00mm_Vertical_SMD
J4: Conn_01x05; PinHeader_1x05_P2.00mm_Vertical
L1: MWSA0603-100MT; L_Sumida_CDMC6D28_7.25x6.5mm; LCSC C132141
Q1: BSC022N04LS6; TDSON-8-1; LCSC C534307
R1: 0R068; R_2512_6332Metric; LCSC C534307
R2: 10k0; R_0805_2012Metric; LCSC C17414
R3: 825k; R_0805_2012Metric; LCSC C17835
R4: 68k1; R_0805_2012Metric; LCSC C17771
R5: 4k75; R_0805_2012Metric; LCSC C17672
R8: 470r; R_0805_2012Metric
TP1, TP4: TestPoint; TestPoint_Pad_1.0x1.0mm
U1: MAX16820ATT; SON95P300X300X80-7N; LCSC C143371
U2: ATtiny1616-M; VQFN-20-1EP_3x3mm_P0.4mm_EP1.7x1.7mm

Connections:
+5V: C4.1, C5.1, C6.1, J4.1, R2.1, R5.2, U1.6 (VCC), U2.4 (VCC)
/LED: D2.1 (K), U2.1 (PA2)
/MODE: J3.2, J3.5, R2.2, U2.5 (PA4)
/PWM: U1.3 (DIM), U2.6 (PA5)
/RXD: J4.4, U2.13 (PB1)
/TXD: J4.5, U2.12 (PB2)
/VMESS: C7.1, R3.2, R4.1, U2.9 (PB5)
GND: C1.2, C2.2, C4.2, C5.2, C6.2, C7.2, J3.3, J3.4, J4.3, Q1.1 (S), Q1.2 (S), Q1.3 (S), R4.2, U1.4 (GND), U1.7 (EP), U2.3 (GND), U2.21 (GND)
unnamed: D1.2 (A), L1.2, Q1.5 (D)
unnamed: D2.2 (A), R5.1
unnamed: J1.1, R1.1, U1.2 (CSN)
unnamed: J2.1, L1.1
unnamed: J4.2, R8.2
unnamed: Q1.4 (G), U1.5 (DRV)
unnamed: TP4.1, U2.15 (PC0)
unnamed: TP1.1, U2.16 (PC1)
unnamed: R8.1, U2.19 (~RESET/PA0)
VCC: C1.1, C2.1, D1.1 (K), J3.1, J3.6, R1.2, R3.1, U1.1 (IN)

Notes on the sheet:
History: - Remove NTC, use CPU internal Sensor - Change VMESS voltage divider to higher Values

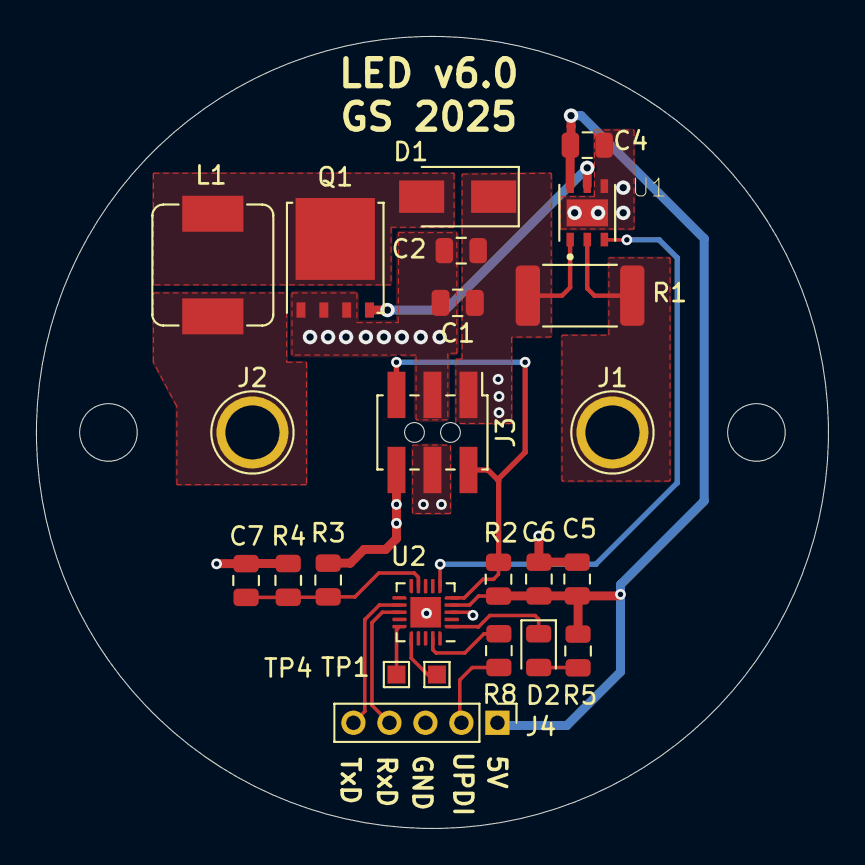
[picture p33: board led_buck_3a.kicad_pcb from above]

Board: 2 copper layers, 44.0 x 44.0 mm, 26 parts (0 on the bottom side), 18 nets.

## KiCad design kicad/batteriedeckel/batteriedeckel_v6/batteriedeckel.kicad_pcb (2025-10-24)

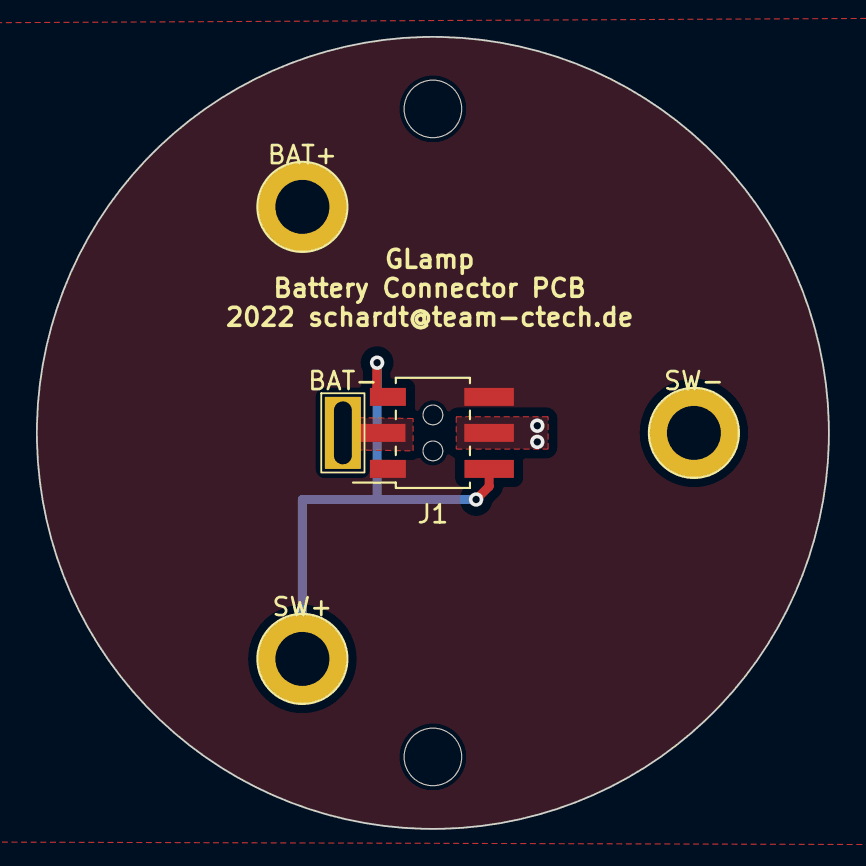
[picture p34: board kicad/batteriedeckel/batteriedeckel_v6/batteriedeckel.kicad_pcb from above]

Board: 2 copper layers, 44.0 x 44.0 mm, 7 parts (0 on the bottom side), 3 nets.

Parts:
BAT+: BAT+; TestPoint_THTPad_D5.0mm_Drill3.0mm
BAT-: BAT-; TestPoint_THTPad_D5.0mm_Drill3.0mm
H1, H2: MountingHole; MountingHole_3.2mm_M3_DIN965
J1: Conn_02x03_Odd_Even; PinSocket_2x03_P2.00mm_Vertical_SMD
SW+: SW+; TestPoint_THTPad_D5.0mm_Drill3.0mm
SW-: SW-; TestPoint_THTPad_D5.0mm_Drill3.0mm

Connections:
/BAT+: BAT+.1, J1.1, J1.6
/GND: BAT-.1, J1.3, J1.4, SW-.1
/MODE: J1.2, J1.5, SW+.1

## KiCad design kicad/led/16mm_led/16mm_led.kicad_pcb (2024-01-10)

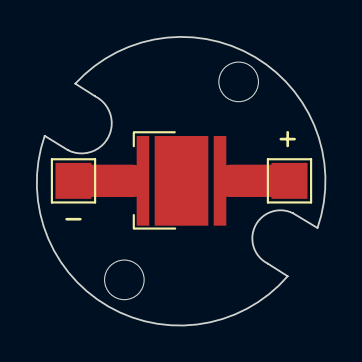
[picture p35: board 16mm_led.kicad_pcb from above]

Board: 2 copper layers, 16.0 x 16.0 mm, 5 parts (0 on the bottom side), 2 nets.

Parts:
D1: LED; LED_Cree-XM
H1, H2: MountingHole; MountingHole_2.2mm_M2
TP1: -; TestPoint_Pad_2.0x2.0mm
TP2: +; TestPoint_Pad_2.0x2.0mm

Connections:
unnamed: D1.1 (K), TP1.1
unnamed: D1.2 (A), TP2.1

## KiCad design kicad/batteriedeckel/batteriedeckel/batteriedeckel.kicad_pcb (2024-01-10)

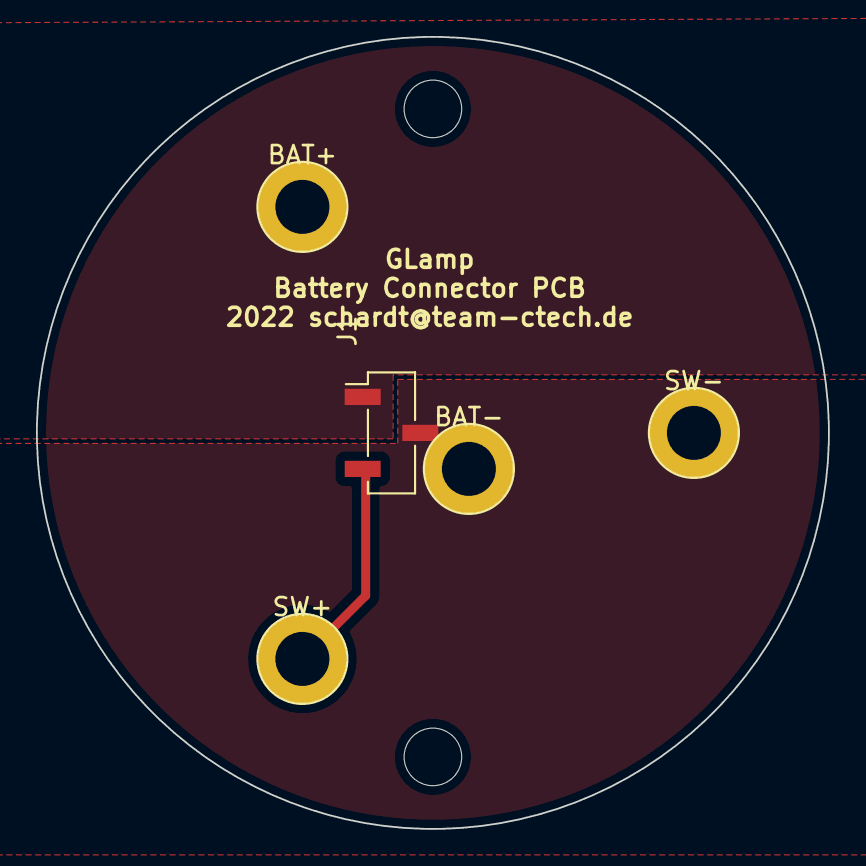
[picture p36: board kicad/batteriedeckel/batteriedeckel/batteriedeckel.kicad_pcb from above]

Board: 2 copper layers, 44.0 x 44.0 mm, 7 parts (0 on the bottom side), 3 nets.

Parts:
BAT+: BAT+; TestPoint_THTPad_D5.0mm_Drill3.0mm
BAT-: BAT-; TestPoint_THTPad_D5.0mm_Drill3.0mm
H1, H2: MountingHole; MountingHole_3.2mm_M3_DIN965
J1: Conn_01x03; PinSocket_1x03_P2.00mm_Vertical_SMD_Pin1Left
SW+: SW+; TestPoint_THTPad_D5.0mm_Drill3.0mm
SW-: SW-; TestPoint_THTPad_D5.0mm_Drill3.0mm

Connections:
/BAT+: BAT+.1, J1.1
/GND: BAT-.1, J1.2, SW-.1
/MODE: J1.3, SW+.1

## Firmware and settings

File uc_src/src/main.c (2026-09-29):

/*
 * Tauchlampe FIX
 * für Buck-Regler MAX16820
 *
 * CPU:
 * ATTINY1616
 *
 * Mikrocontroller Code:
 * Version 5.1
 *
 *
 * History:
 * 2025-10-24   HW v6.0 ready
 * 2022-09-30   CPU Wechsel für V5 auf ATTINY1616
 * 2022-10-27   NTC Zweig abgeklemmt. Nutze CPU T Sensor
 *              IDLE Stromaufnahme bei 230u
 * 
 */
#include "led_buck_3a.h"
#include <avr/io.h>
#include <avr/interrupt.h>
#include <avr/eeprom.h>
#include <avr/sleep.h>
#include "util/delay.h"
#include "util/atomic.h"
#include "string.h"
#include "stdbool.h"


/*
    ADC_VAL     Wert
    0           Internal T-Sensor
    1           Eingangsspannung
    2           PCB Temperatur
*/
volatile uint16_t ADC_VAL[2];
// wird vom ADC ISR gesetzt sobald ein kompletter Durchlauf (Temp + VCC)
// vorliegt. Nur dann darf CheckConditions() die Werte auswerten.
volatile bool adc_newData = false;

volatile uint8_t batteryStatus = BAT_OK;
volatile uint8_t newLevel = PWM_AUS;
volatile uint8_t pwmLevel = PWM_AUS;
volatile bool isOvertemp = false;
volatile uint32_t ms_ticks = 0;
volatile uint32_t but_ticks = 0;
// nur von CheckConditions() angefasst, deshalb nicht volatile.
// Reset laeuft ueber das Flag voltminReset (float ist nicht atomar).
static float voltmin = 14.0;
volatile bool voltminReset = false;
volatile bool pressed = false;

//1ms tick
ISR(TCB1_INT_vect)
{
    static uint32_t msec = 0;

    msec++;
    ms_ticks++;
    but_ticks++;
    //starte alle 1000ms ADC Lauf
    if ( (msec%1000) == 0){
        ADC0.COMMAND = ADC_STCONV_bm;
    }

    switch (batteryStatus) {
            case BAT_EMPTY:
                if ((msec % 100) == 0) {
                    LED_PORT.OUTTGL = LED_PIN_bm;
                }
                break;
            case BAT_LOW:
                if ((msec % 800) == 0) {
                    LED_PORT.OUTTGL = LED_PIN_bm;
                }
                break;
            case BAT_HALF:
                LED_PORT.OUTCLR = LED_PIN_bm;
                break;
            case BAT_OK:
                LED_PORT.OUTSET = LED_PIN_bm;
                break;
        }


    //interrupt flag löschen
    TCB1.INTFLAGS = TCB_CAPT_bm;
}

ISR (ADC0_RESRDY_vect) 
{
    static uint8_t chan_sel = 0;
    uint16_t val;
    
    val = ADC0.RES >> ADC_SHIFT_DIV64;
    switch (chan_sel) {
        case ADC_CHAN_TEMP_INTERNAL: 
            ADC_VAL[0] = val;
            ADC0.MUXPOS = ADC_MUXPOS_AIN8_gc;
            chan_sel = ADC_CHAN_VCC;
            ADC0.COMMAND = ADC_STCONV_bm;
            break;
        
        case ADC_CHAN_VCC:
            ADC_VAL[1] = val;
            ADC0.MUXPOS = ADC_MUXPOS_TEMPSENSE_gc;
            chan_sel = ADC_CHAN_TEMP_INTERNAL;
            adc_newData = true;
            break;
    }
}

ISR (PORTA_PORT_vect)
{
    //flags zurücksetzen
    uint8_t flags = PORTA.INTFLAGS;
    static unsigned wait;


    if (! (MODE_PORT.IN & MODE_PIN_bm) ) {
        PORTA.INTFLAGS = flags;   
        return; 
    }
    //fallende Flanke
    if (flags & MODE_PIN_bm) {
        if (pwmLevel == PWM_AUS) {
            if (!pressed) {
                pressed = true;
                but_ticks = 0;
                PORTA.INTFLAGS = flags;
                return;
            } else {
                if (but_ticks < WAIT_TIME) {
                    PORTA.INTFLAGS = flags;
                    return;
                }
                wait = ms_ticks;                
                pressed=false;
              //weiter machen
            }
        } else {
            // letzter klick mehr als 300ms her
            if (ms_ticks - wait > WAIT_TIME) {
                wait = ms_ticks;
            // sonst warten
            } else {
                PORTA.INTFLAGS = flags;
                return;
            }
        }

        switch (pwmLevel) {
            case PWM_AUS:
				//reset minmum voltage
				voltminReset = true;
                newLevel = PWM_MAX;
                break;
            case PWM_MAX:
                newLevel = PWM_70;
                break;
            case PWM_70:
                newLevel = PWM_30;
                break;
            case PWM_30:
                newLevel = PWM_AUS; 
                break;
            default:
                newLevel = PWM_AUS;
        }
    }
    //lösche interrupt flag
    PORTA.INTFLAGS = flags;
}

void USART0_sendChar(char c) 
{
    while (!(USART0.STATUS & USART_DREIF_bm));

    USART0.TXDATAL = c;
}

void USART0_sendString(const char *str)
{
    for(size_t i = 0; i < strlen(str); i++) {
        USART0_sendChar(str[i]);
    }
}

#if DEBUG_UART
// vorzeichenbehaftete Dezimalausgabe ohne printf (spart Flash und Stack)
static void USART0_sendInt(int32_t v)
{
    char buf[12];
    uint8_t i = 0;

    if (v < 0) {
        USART0_sendChar('-');
        v = -v;
    }
    do {
        buf[i++] = '0' + (char)(v % 10);
        v /= 10;
    } while (v);
    while (i) USART0_sendChar(buf[--i]);
}

// Ausgabe z.B.:  ADC=766 U=10802mV Umin=10750mV T=41C
void USART0_sendMeasurement(uint16_t raw, float u, float umin, int16_t temp)
{
    USART0_sendString("ADC=");
    USART0_sendInt(raw);
    USART0_sendString(" U=");
    USART0_sendInt((int32_t)(u * 1000.0 + 0.5));
    USART0_sendString("mV Umin=");
    USART0_sendInt((int32_t)(umin * 1000.0 + 0.5));
    USART0_sendString("mV T=");
    USART0_sendInt(temp);
    USART0_sendString("C\r\n");
}
#endif

void setPWM(uint8_t level)  //level in Prozent
{
    uint8_t val = (uint8_t)((255 * level)/100);

    if (level == 0) {
        TCB0.CTRLB &= ~TCB_CCMPEN_bm;
        TCB0.CTRLA &= ~TCB_ENABLE_bm;
        PORTA_OUT &= ~PIN5_bm;
    } else if (level == 100) {
        TCB0.CTRLB &= ~TCB_CCMPEN_bm;
        TCB0.CTRLA &= ~TCB_ENABLE_bm;
        PORTA_OUT |= PIN5_bm;
    } else {
        TCB0.CTRLB |= TCB_CCMPEN_bm;
        TCB0.CCMP = (val << 8) | 0xff;
        TCB0.CTRLA |= TCB_ENABLE_bm;
    }
}

void startup(uint8_t val) 
{
    //disable Portchange interrupt during startup
    PORTA.PIN4CTRL &= ~PORT_ISC_BOTHEDGES_gc;
    for (uint8_t i = 0; i < val; i++) {
        if (newLevel == PWM_AUS) {
            pwmLevel = PWM_AUS;
            setPWM(pwmLevel);
            //reactivate Interrupt
            PORTA.PIN4CTRL |= PORT_ISC_BOTHEDGES_gc;
            return;
        }
        setPWM(i);
        _delay_ms(10);
    }
    PORTA.PIN4CTRL |= PORT_ISC_BOTHEDGES_gc;
}

// Rohwert wird uebergeben, damit der Wert nicht waehrend der Rechnung
// vom ADC ISR ueberschrieben werden kann.
int16_t getOnChipTemperature(uint16_t adc_raw)
{
    int8_t  sigrow_offset = SIGROW.TEMPSENSE1;
    uint8_t sigrow_gain = SIGROW.TEMPSENSE0;

    uint32_t temp = adc_raw - sigrow_offset;
    temp *= sigrow_gain;
    temp += 0x80;
    temp >>= 8;                 // temp ist jetzt Kelvin

    // ohne Clamp wuerde ein Wert < 273K (z.B. vor der ersten Messung)
    // unterlaufen und faelschlich Uebertemperatur ausloesen
    if (temp < 273) return -273;
    return (int16_t)(temp - 273);
}

uint8_t CheckConditions(void)
{
    // Default MAX: solange keine gueltige Messung vorliegt darf nicht
    // gedimmt werden (vorher stand hier PWM_AUS)
    static uint8_t dimmlevel = PWM_MAX;
    // zuletzt zurueckgegebenes Ergebnis inkl. Uebertemperatur-Begrenzung
    static uint8_t result = PWM_MAX;
    static uint8_t cnt = 0;
    uint16_t adc_vcc, adc_temp;
    int16_t temperature;
    float u_vcc;

    if (voltminReset) {
        voltminReset = false;
        voltmin = 14.0;
        cnt = 0;
    }

    // CheckConditions() wird in der Hauptschleife sehr oft pro Sekunde
    // aufgerufen, der ADC liefert aber nur 1x/s. Ohne diese Abfrage lief
    // der Zaehler unten in Mikrosekunden durch und ein einziger zu
    // niedriger Messwert (Lastspitze, Einschaltstrom) wurde sofort und
    // dauerhaft als voltmin uebernommen -> Lampe dimmt und kommt nicht
    // wieder hoch.
    if (!adc_newData) {
        return result;
    }

    // 16 Bit Werte atomar uebernehmen, sonst kann der ADC ISR zwischen
    // Low- und High-Byte zuschlagen und einen Muellwert liefern
    ATOMIC_BLOCK(ATOMIC_RESTORESTATE) {
        adc_temp = ADC_VAL[ADC_CHAN_TEMP_INTERNAL];
        adc_vcc  = ADC_VAL[ADC_CHAN_VCC];
        adc_newData = false;
    }

    u_vcc = ADC_TO_VOLT(adc_vcc);
    temperature = getOnChipTemperature(adc_temp);

#if DEBUG_UART
    USART0_sendMeasurement(adc_vcc, u_vcc, voltmin, temperature);
#endif

    // immer die Min Voltage nach einschalten nehmen
    // und 10 Messungen ~ 10 Sekunden warten eh Wert uebernommen wird
    if (u_vcc < voltmin) {
       if (cnt++ > 10) voltmin = u_vcc;
    } else
        cnt = 0;

    //Overtemp geht vor Voltage
    if (isOvertemp ) {
        if (temperature < OVERTEMP_LOW) {
            isOvertemp = false;
        }
    } else {
        if (temperature > OVERTEMP_HIGH) {
            isOvertemp = true;
        } 
    }
    //Batterieladung prüfen
    if (voltmin < V_AUS) {
        batteryStatus = BAT_EMPTY;
        dimmlevel = PWM_AUS;
    } else if (voltmin < V_LEER) {
        batteryStatus = BAT_LOW;
        dimmlevel = PWM_MIN;
    } else if (voltmin < V_HALB) {
        batteryStatus = BAT_HALF;
        dimmlevel = PWM_MAX;
    } else {
        batteryStatus = BAT_OK;
        dimmlevel = PWM_MAX;
    }
    if (isOvertemp && (dimmlevel > PWM_OVERTEMP)) {
        result = PWM_OVERTEMP;
    } else {
        result = dimmlevel;
    }

    return result;

}

void gotoSleep(void) {

    
    pressed = false;
    PORTA.PIN4CTRL |= PORT_ISC_BOTHEDGES_gc;
    LED_PORT.OUTSET = LED_PIN_bm;
    set_sleep_mode(SLEEP_MODE_PWR_DOWN);
    sleep_enable();
    sleep_cpu();
    sleep_disable();
}


void port_init() 
{
    //PORT A Pins
    PORTA.DIR = 0xFF; //all out
    //PWM Pin low
    PORTA_OUT &= ~PIN5_bm;
    PORTA.DIR &= ~PIN4_bm; //Pin 4 Input -> Mode
    
    //UART Config
    PORTB.DIR = 0x1F;  // Pin 5 input

    //Analog in    
    PORTB.PIN5CTRL &= ~PORT_ISC_gm;
    PORTB.PIN5CTRL |= PORT_ISC_INPUT_DISABLE_gc;
    PORTB.PIN5CTRL &= ~PORT_PULLUPEN_bm;

    //Port C
    PORTC.DIR = 0xF; //all out
}

void init() 
{
    //set clock to 3.3 MHz (20MHz / 6 Prescaler)
    _PROTECTED_WRITE(CLKCTRL.MCLKCTRLA, CLKCTRL_CLKSEL_OSC20M_gc);
    _PROTECTED_WRITE(CLKCTRL.MCLKCTRLB, CLKCTRL_PDIV_6X_gc | CLKCTRL_PEN_bm);

    //ADC config
    // Der Spannungsteiler hat mit 825k/68k1 eine Quellimpedanz von ~63k.
    // Der ADC laedt bei jedem Sample seinen S&H Kondensator aus diesem
    // Knoten nach. Bei schnellem Takt ergibt das einen mittleren
    // Eingangsstrom, der ueber 63k einen deutlichen Spannungsabfall
    // erzeugt -> der ADC misst systematisch zu wenig und die Lampe dimmt
    // zu frueh. Deshalb: kleiner S&H Kondensator, langsamer ADC Takt und
    // lange Sample-Zeit.
    VREF.CTRLA = VREF_ADC0REFSEL_1V1_gc;
    // SAMPCAP: laut Datenblatt bei Referenz > 1,0V zu setzen (halbiert C_S&H)
    // PRESC_DIV32: CLK_ADC = 3,3MHz/32 = 103kHz (zulaessig 50k..1,5M)
    ADC0.CTRLC = ADC_SAMPCAP_bm | ADC_PRESC_DIV32_gc | ADC_REFSEL_INTREF_gc;
    ADC0.CTRLA = ADC_ENABLE_bm | ADC_RESSEL_10BIT_gc;
    ADC0.MUXPOS = ADC_MUXPOS_TEMPSENSE_gc;
    ADC0.CTRLB = ADC_SAMPNUM_ACC64_gc;
    // Einschwingzeit der Referenz und nach Kanalwechsel abwarten
    ADC0.CTRLD = ADC_INITDLY_DLY64_gc;
    // SAMPLEN = 31 -> Sample-Fenster 33 CLK_ADC = 320us.
    // Deckt auch die vom Temperatursensor geforderten min. 32us ab.
    ADC0.SAMPCTRL = 0x1F;
    ADC0.INTCTRL = ADC_RESRDY_bm;  //interrupt activieren
    ADC0.COMMAND = ADC_STCONV_bm;

    //TMR B1 for 1ms ticks
    TCB1.CTRLA = TCB_CLKSEL_CLKDIV1_gc | TCB_ENABLE_bm;   
    TCB1.INTCTRL = TCB_CAPT_bm;
    TCB1.CCMP = 3370;
    //TMR B0 for PWM
    TCB0.CCMP = 0x80FF;
    TCB0.CTRLA |= TCB_CLKSEL_CLKDIV1_gc;
    TCB0.CTRLB |= TCB_CCMPEN_bm | TCB_CNTMODE_PWM8_gc;


    //UART Config
    USART0.BAUD = (uint16_t)USART0_BAUD_RATE(9600);
    USART0.CTRLB |= USART_TXEN_bm;
    TCA0.SINGLE.CTRLA = TCA_SINGLE_CLKSEL_DIV4_gc | TCA_SINGLE_ENABLE_bm;
    
    ADC0.COMMAND = ADC_STCONV_bm;
    _delay_ms(10);
    //Interrupt enable
    sei();    
 
}

void main ()
{
    bool tank_start = false;
    
    port_init();
    init();
  
    //check mode pin
    //HIGH beim starten -> Akkufach
    if (MODE_PORT.IN & MODE_PIN_bm) {
        pwmLevel = PWM_AUS;
        setPWM(pwmLevel);
        //Akkufach hat Taster, interrupt aktivieren
        PORTA.PIN4CTRL |= PORT_ISC_BOTHEDGES_gc;
        gotoSleep();
        

    //LOW beim starten -> Akkutank
    } else {
        tank_start = true;
        newLevel = eeprom_read_byte(DIMSTATE_ADDR);
        if (newLevel == 0) newLevel = PWM_MAX; //first time 
        switch (newLevel) {
            case PWM_MAX:
                eeprom_update_byte(DIMSTATE_ADDR, PWM_70);
                break;
            case PWM_70:
                eeprom_update_byte(DIMSTATE_ADDR, PWM_30);
                break;
            case PWM_30:
                eeprom_update_byte(DIMSTATE_ADDR, PWM_MAX);
                break;
            default:
                eeprom_update_byte(DIMSTATE_ADDR, PWM_MAX);
                break;
        }
        //new Level ist gewünschtes Level, pwmLEvel maximal mögliches
        pwmLevel = CheckConditions();
        if (pwmLevel >= newLevel)
            pwmLevel = newLevel;
        startup(newLevel);
    }
    
    ms_ticks = 0;
    while (1) {
        if ((ms_ticks > 10000) && tank_start) {
            tank_start = false;
            eeprom_update_byte(DIMSTATE_ADDR, PWM_MAX);
        }
        //Lampe aus
        if (pwmLevel == PWM_AUS) {
            if (ms_ticks < WAIT_TIME*2) {
                pressed = 0;
                continue; // entprellen des letzten klicks vor aus, damit doppelclick für an geht
            } 
            if (but_ticks > 1100)  //Zweiter Klick kam nicht
            gotoSleep();
          
            if (newLevel > PWM_AUS) {
                pwmLevel = CheckConditions();
                if (pwmLevel >= newLevel)
                    pwmLevel = newLevel;  // CheckConditions erlaubt höheren dimmwert
                startup(pwmLevel);
            }
        // Lampe an
        } else {
            if (newLevel > PWM_AUS) {
                pwmLevel = CheckConditions(); 
                if (pwmLevel >= newLevel)
                    pwmLevel = newLevel;  // CheckConditions erlaubt höheren
                                        // dimmwert
            } else {
                pwmLevel = newLevel;
                ms_ticks = 0;
            }
            setPWM(pwmLevel);
        }
     }

}

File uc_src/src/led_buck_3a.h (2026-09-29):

/*
 * Tauchlampe FIX
 * für Buck-Regler MAX16820
 * 
 */
#include <avr/io.h>

#define SW_VERSION_MAJOR    5
#define SW_VERSION_MINOR    1

#define F_CPU   3300000UL // 20Mhz clock speed / 6 prescaler
#define USART0_BAUD_RATE(BAUD_RATE) ((float)(F_CPU * 64 / (16 * (float)BAUD_RATE)) + 0.5)
#define ADC_SHIFT_DIV64 (6)

#define ADC_CHAN_TEMP_INTERNAL  0
#define ADC_CHAN_VCC            1

// Spannungsteiler VMESS (VCC -> R3 -> VMESS -> R4 -> GND), HW v6
// ACHTUNG: Quellimpedanz = R1||R2 = 62,9k. Das ist weit ueber dem, was der
// ADC bei Default-Timing treiben kann -> ADC0 laeuft deshalb langsam
// (PRESC_DIV32) mit verlaengerter Sample-Zeit (SAMPLEN=31, SAMPCAP=1).
#define R_MESS_1 825000.0   // R3
#define R_MESS_2 68100.0    // R4 (68k1 laut BOM)
#define U_ADC_REF 1.1
// Korrekturfaktor fuer die Toleranz der internen 1,1V Referenz (+-3%).
// Ermittlung: U_gemessen(Multimeter) / U_ausgegeben(UART) -> hier eintragen.
// 2026-09-29 auf HW v6 gegen Multimeter geprueft: die UART-Ausgabe stimmt
// auf wenige mV, es ist also keine Korrektur noetig -> bleibt bewusst 1.0.
#define U_CAL 1.0

// Rohwert (auf 10 Bit normiert) -> Batteriespannung in Volt
#define ADC_TO_VOLT(adc)    ( (float)(adc) * (float)(U_ADC_REF / 1024.0) \
                              * (float)((R_MESS_1 + R_MESS_2) / R_MESS_2) \
                              * (float)U_CAL )

enum { BAT_OK = 0, BAT_HALF, BAT_LOW, BAT_EMPTY };

// Max, Min und Hysterese Werte
#define PWM_MAX 100       // Dimm-Level	MAX
#define PWM_70 70
#define PWM_OVERTEMP 30  //			    bei �berTemperatur
#define PWM_30 30
#define PWM_MIN 20        //				bei Unterspannung
#define PWM_AUS 0  //				bei starkter Unterspannung

// Ladeschlußspannung 4,2V, Entladeschlussspannung 2,75V, 3 in Serie
#define V_HALB 10.5
#define V_LEER 9.2  // Akku fast leer Spannung in Volt, ab hier Dimmen
#define V_AUS 8.5   // Akku leer Spannung in Volt

#define OVERTEMP_HIGH   70
#define OVERTEMP_LOW    60

#define DIMSTATE_ADDR 0

#define WAIT_TIME 300   //entprellzeit in ms

// Hardware Pins
#define LED_PORT PORTA
#define LED_PIN 2
#define LED_PIN_bm  PIN2_bm
#define PWM_PORT PORTA
#define PWM_PIN 5
#define MODE_PORT PORTA
#define MODE_PIN_bm PIN4_bm

// HW v6: VMESS haengt an PB5 = AIN8. PB4 ist unbeschaltet.
// Der NTC-Zweig entfaellt, es wird der CPU-interne Sensor benutzt.
#define VMESS_PORT PORTB
#define VMESS_PIN 5
#define VMESS_ADC_CHAN 8

// 1 = einmal pro Messung Rohwert/Spannung/Temperatur auf UART ausgeben
// (nur zum Debuggen/Kalibrieren einschalten, im Normalbetrieb 0)
#define DEBUG_UART 0

#define UART_BAUD 9600
#define UART_RX_PORT PORTB
#define UART_RX_PIN 1
#define UART_TX_PORT PORTB
#define UART_TX_PIN 2

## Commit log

2020-11-12 Frisch aufgeräumt
    [Bauteil1.0003.ipt, Bauteil1.ipt, Bauteil1.stl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]
2020-11-13 Zeichnung fertig gestellt Aufbau Dokument begonnen
    [Lampenkopf.0013.idw, Lampenkopf.idw]
2020-11-13 Explosionszeichnung neu O-Ringe hinzugefügt
    [Lampenkopf.0002.ipn, Lampenkopf.0016.idw, Lampenkopf.0031.iam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]
2020-11-13 STLs für 3D Druckteile hinzugefügt
    [akkufach_deckel.stl, led_deckel.stl]
2020-11-17 uc_src angepasst
    [Lampenkopf.ipn, Lampenkopf_exp.idw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]
2020-12-01 change some parts to non-china parts add some gnd vias to JST connector add new chapter to Aufbau.pdf port uc firmware to new Uc
    [MAX16819_CALC.xls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]
2021-01-17 Fix sleep mode with battery pack
    [buck_3a_v4.kicad_pcb, buck_3a_v4.sch]
2021-04-16 mech/ Lampengehäuse getauscht zu Variante mit O-Ring
    kicad/
    Neue Version mit besserem Layout
    Neue JLC Daten
    [buck_3a_v4-B_CrtYd.gbr, buck_3a_v4-B_Cu.gbr, buck_3a_v4-B_Mask.gbr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]
2021-05-04 3A Regler V4 tested with JLC Parts
    [buck_3a_v4.kicad_pcb, buck_3a_v4.sch, digikey.ods]
2021-10-25 main.c: add sleep_bod_disable()
    [digikey.ods]
2022-09-15 Save V4.3
    [BOM-buck_3a_v4.csv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]
2022-09-19 change kicad folder
    [BOM-batteriedeckel.csv, BOM-buck_3a_v4.csv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]
2022-10-26 Software v5
    [Material.ods]
2024-01-10 - Neues PCB V5.1 - Ädernungen an den Akkufach 3D Teilen - Firmware überarbeitet
    [16mm_led-CuBottom.gbr, 16mm_led-CuTop.gbr, 16mm_led-EdgeCuts.gbr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]
2024-01-10 Neue Mechanik hinterlegt
    [ASPI-7318-100M-T--3DModel-STEP-400430.iam, B3B-PH-SM4-TB-LF--SN---3DModel-STEP-56544.iam, Bauteil1.0003.ipt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]
2025-10-24 clean up
    [BOM-batteriedeckel.csv, BOM-led_buck_3a.csv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]
2026-09-29 Spannungsmessung auf HW v6 angepasst und verifiziert
    VMESS liegt jetzt auf PB5/AIN8, der NTC-Zweig entfaellt zugunsten des
    CPU-internen Temperatursensors. R4 auf 68k1 laut BOM korrigiert und die
    Umrechnung in das Makro ADC_TO_VOLT mit Kalibrierfaktor U_CAL gezogen.
    Wegen der Quellimpedanz von 62,9k laeuft ADC0 mit PRESC_DIV32 und
    verlaengerter Sample-Zeit.
    Gegen Multimeter geprueft: die UART-Ausgabe stimmt auf wenige mV,
    U_CAL bleibt deshalb bewusst 1.0.
    [led_buck_3a.h, main.c]
2026-09-29 DEBUG_UART wieder abschalten
    Die Messwertausgabe auf dem UART war nur zum Kalibrieren noetig.
2026-09-29 .gitignore selbst versionieren und toten Eintrag entfernen
    Die Datei hat sich bisher selbst ignoriert und war damit nicht im Repo -
    bei einem frischen Clone waren alle Regeln weg.
    kicad/v5/led_buck_3a-backups/ zeigte ins Leere, seit v5 nach
    ZZ_Archiv/kicad/ verschoben wurde.
2026-09-29 KiCad-Backups generell ignorieren und aus der Versionierung nehmen
    Statt einzelner Pfade jetzt *-backups/ und _autosave-*, das greift in
    jedem KiCad-Projekt. Die 48 bereits versionierten Backup- und
    Autosave-Dateien per git rm --cached entfernt; auf der Platte bleiben
    sie liegen.
2026-09-29 Alte PCB-Revisionen v4 und v5 ins Archiv verschoben
    Die Projekte liegen jetzt unter ZZ_Archiv/kicad/v4 bzw. v5 und sind damit
    wie der Rest des Archivs nicht mehr versioniert. Auf der Platte bleiben
    sie vollstaendig erhalten, der letzte Stand bleibt ueber die History
    erreichbar.
    [BOM-buck_3a_v4.csv, BOM-led_buck_3a.csv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]
2026-09-29 Kabeladapter-Projekt aufnehmen
    Neues KiCad-Projekt fuer den Kabeladapter, beim Import war es doppelt
    verschachtelt (kabeladapter/kabeladapter) - jetzt flach unter kicad/.
    Backups und Autosave-Dateien bleiben per .gitignore draussen.
    [BOM-led_buck_3a.csv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]
2026-09-29 KiCad-Projektdatei v6: neue Schluessel der aktuellen KiCad-Version
    Beim Oeffnen ergaenzte Defaults - 15 neue ERC-Regeln sowie Annotations-,
    BOM- und Darstellungsoptionen. Keine Aenderung an Netzklassen, Design
    Rules oder Layout.
